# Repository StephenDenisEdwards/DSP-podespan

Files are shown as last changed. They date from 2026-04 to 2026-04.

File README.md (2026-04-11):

# DSP + DPS — Novostavba RD Edwards, Jevany

Complete building permit documentation (DSP — Dokumentace pro stavebni povoleni + DPS — Dokumentace pro provadeni stavby) for a new family house in Jevany, Czech Republic.

## Project Details

| | |
|---|---|
| **Project** | Novostavba rodinneho domu (New family house) |
| **Location** | Jevany [533378], k.u. Jevany [659312], parcels 154/10 and 154/16 |
| **Investor** | Bc. Marketa Edwards |
| **Design firm** | LUCERN DREVOSTAVBY s.r.o., Praha 4 - Branik |
| **Construction type** | Timber-frame (drevostavba), LUCERN EKO PLUS system |
| **Lead designer** | Ing. Josef Frydryn |
| **Authorized by** | Ing. Milos Slavik (2026-03-09) |
| **Elevation reference** | +/-0,000 = 397.402 m n. m. (Bpv) |

## Building Summary

Single-storey family house with attached garage on a sloping garden site (1,091 m2).

- **House footprint:** 180.38 m2
- **Usable area:** 142.07 m2 (4 bedrooms, open-plan living/kitchen, 2 bathrooms, utility room)
- **Terrace:** 38.18 m2
- **Garage:** 18.00 m2
- **Site coverage:** 15.67%
- **Remaining green area:** 84.33%

## Repository Structure

```
A. Pruvodni list/                  Cover / introductory report
B. Souhrnna technicka zprava/      Summary technical report
C. Situacni vykresy/               Site plans (C.1-C.4)
D.1. Dokumentace stavebniho objektu/
    D.1.1. Architektonicko stavebni cast/   Architecture (13 drawings)
    D.1.2. Stavebne konstrukcni cast/       Structural engineering
    D.1.3. Pozarni bezpecnost staveb/       Fire safety
    D.1.4. Technika prostredi staveb/
        D.1.4.1. Zdravotne technicke instalace/  Plumbing (5 docs)
        D.1.4.2. Vytapeni/                       Heating (2 docs)
        D.1.4.3. Elektroinstalace/               Electrical (3 docs)
        D.1.4.4. Nucene vetrani/                  Ventilation (2 docs)
E. Dokladova cast/                 Supporting documents
    GEOLOGICKY PRUZKUM/                Geological survey
    PENB/                              Energy performance certificate
    RADON/                             Radon report
_TITULKY/                          Title / cover pages
Documents/                         Analysis, tools, and working notes
    dwg-files/                         Survey plan (DXF/DWG) and tools
```

## Survey Plan & CAD Tools

The geodetic survey plan (`Documents/dwg-files/10225.dxf`) is the primary working file for site design. It contains terrain elevations, parcel boundaries, and existing features in S-JTSK coordinates.

**Tools included:**

- `visualize_dxf.py` — Generic DXF visualizer. Usage: `python visualize_dxf.py [file.dxf]`
- `create_site_plan.py` — Overlays the building footprint on the survey plan (approximate placement based on C.3 dimensions and elevation matching)

## Documents

| Document | Description |
|---|---|
| [Survey Plan Analysis](Documents/Survey%20Plan%20Analysis%20-%2010225.md) | Detailed analysis of the geodetic survey plan |
| [Swimming Pond - Project Design Document](Documents/Swimming%20Pond%20-%20Project%20Design%20Document.md) | Consolidated feasibility, geotechnical assessment, and technical design specification for the swimming pond |
| [CAD Workflow and File Status](Documents/CAD%20Workflow%20and%20File%20Status.md) | CAD file tracking, DXF analysis, coordinate system issues, and project context |
| [Natural Swimming Ponds Reference](Documents/reseach/natural-swimming-ponds-reference.md) | Comprehensive reference guide: design principles, construction, planting, regulations, costs (UK/EU) |
| [Image Generation Prompt](Documents/image-generation-prompt.md) | AI visualization prompt specifications for the house and pond |

## Key Site Data

| Parameter | Value |
|---|---|
| Site area | 1,091 m2 (parcels 154/10 + 154/16) |
| Terrain elevation | 392.7 - 399.6 m ASL |
| Slope | ~7 m fall over ~100 m (S to N) |
| Soil type | F5 ML (low-plasticity silt/clay), stiff consistency |
| Groundwater | ~7 m below ground |
| Soil permeability (kv) | 5.0 x 10-6 m/s |
| Radon index | HIGH |
| Coordinate system | S-JTSK (EPSG:5514) |

## Tools & Services

### Online Viewers

| Tool | URL | Purpose |
|---|-----|---|
| **Autodesk Viewer** | https://viewer.autodesk.com | Free online viewer for DWG, DXF, and PDF files — no software install required. Upload files to inspect layers, measure geometry, and navigate 2D/3D drawings in the browser. |

### CAD Software

| Tool | Purpose |
|---|---|
| **AutoCAD** | Industry-standard CAD software. The DWG files originate from AutoCAD (AC1027 / AutoCAD 2013 format). |
| **ODA File Converter** | Free tool from the Open Design Alliance for batch converting between DWG and DXF without an AutoCAD licence. Download from https://www.opendesign.com/guestfiles/oda_file_converter |

### Python Libraries

| Library | Purpose |
|---|---|
| **ezdxf** | Read, write, and manipulate DXF files programmatically. Used by `visualize_dxf.py` and `create_site_plan.py`. Install: `pip install ezdxf` |
| **matplotlib** | Plotting and PNG export of DXF visualizations. Install: `pip install matplotlib` |
| **numpy** | Numerical operations for coordinate and geometry processing. Install: `pip install numpy` |

### PDF Processing (optional)

| Library | Purpose |
|---|---|
| **pdfplumber** | Extract text and tables from PDF documents. Install: `pip install pdfplumber` |
| **PyPDF2** | PDF merging, splitting, and metadata extraction. Install: `pip install PyPDF2` |
| **PyMuPDF (fitz)** | High-performance PDF rendering and text extraction. Install: `pip install PyMuPDF` |

### Coordinate Systems

| System | Code | Description |
|---|---|---|
| **S-JTSK** | EPSG:5514 | Czech national geodetic coordinate system used in all survey and site plan files |
| **Bpv** | — | Baltic Vertical Datum — elevation reference for all height data |

## Source Files

The original project files are available at:
[Dropbox — DSP + DPS original files](https://www.dropbox.com/scl/fo/dlxxf2gikck120so64mw4/ANBmE9GKqDEZeK-OOHEcK_o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)

## Next Steps

1. Obtain remaining DWG files from LUCERN DREVOSTAVBY (see [CAD Workflow](Documents/CAD%20Workflow%20and%20File%20Status.md))
2. Create accurate combined site plan with exact building footprint
3. Design natural swimming pond layout on the DXF base

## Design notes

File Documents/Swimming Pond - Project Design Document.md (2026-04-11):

# Natural Swimming Pond (Schwimmteich) - Project Design Document

**Date:** 2026-04-11
**Site:** Parcels 154/10 and 154/16, Jevany [533378]
**Owner:** Bc. Marketa Edwards
**Coordinate system:** S-JTSK (Krovak)
**Elevation datum:** Bpv (Baltic after adjustment)

---

## Part A: Feasibility Assessment

### A.1 Key Documents and What to Use Them For

#### Primary Design Base

| Document | What it tells you | Priority |
|---|---|---|
| **10225.dxf** (survey plan) | Terrain elevations, parcel boundaries, existing features. Base drawing for design. | Essential |
| **C.3 Situace koordinacni** | Building footprint, utility routes, setbacks. Shows where things are and what space remains. | Essential |
| **Geologicky pruzkum** (E.) | Soil layers, permeability, groundwater depth. Determines feasibility and construction method. | Essential |

#### Supporting Information

| Document | What it tells you |
|---|---|
| **C.2 Situace celkova** | Parcel areas, neighbouring parcels, access, overall layout |
| **Radon report** (E.) | Soil gas permeability, confirms soil type across site |
| **D.1.4.1.4 Schema destove kanalizace** | Existing rainwater drainage routes; potential integration |
| **D.1.4.1.1 Technicka zprava** | Water supply connection, soakaway design, pipe routes |
| **D.1.1.1 Technicka zprava** | Building technical report, finished floor levels |

### A.2 Available Space

| Metric | Value |
|---|---|
| Total site area | 1,091 m² |
| House footprint | 180.38 m² |
| Paved areas + terrace + garage | 170.94 m² |
| Remaining green area | **739.68 m²** (approx.) |
| Green area percentage | 84.33% (per zoning) |

The site is elongated, running roughly NW-SE from Prazska street. The house sits toward the NW corner. The majority of open space is to the **east and southeast** of the building.

### A.3 Feasibility Factors

#### Factors in Favour

1. **Plenty of space** — 740 m² of green area; the proposed 75 m² pond uses only ~10% of available space
2. **Deep water table (7 m)** — no risk of groundwater contamination or buoyancy/flotation of an empty pond
3. **Stiff clay soil (F5 ML)** — naturally low permeability; clay soils are the best natural base for ponds
4. **No public stormwater sewer** — rainwater is already managed on-site; a pond could integrate with the existing retention/infiltration strategy
5. **Sloping terrain** — allows gravity-fed circulation between regeneration and swimming zones
6. **Granite-derived soil** — chemically neutral to slightly acidic; suitable for aquatic planting

#### Factors to Address

1. **Soil permeability (kv = 5 x 10⁻⁶ m/s)** — not zero; additional sealing required (see Part B §B.4)
2. **Terrain slope** — unequal cut depths; downhill side needs retaining solutions or naturalistic grading
3. **Fill material to 1.80 m** — upper soil is anthropogenic fill (navazka); pond base should reach natural clay below
4. **Existing utility routes** — electricity 82 m, water 81 m, sewer 40 m, rainwater 57 m; pond must clear these
5. **Radon** — HIGH index (72.3 kBq/m³); not a concern for open-air pond, but enclosed pump chambers would need protection
6. **Setbacks from boundaries** — Czech regulations typically require setbacks for water features; must confirm with stavebni urad (see Part B §B.6)
7. **Winter conditions** — Jevany at ~400 m ASL; hard frosts expected; sufficient depth (2.0 m) prevents freezing solid
8. **Building proximity** — pond at 0.1 m from terrace; pond floor ~1.2 m below house foundation base (see Part B §B.5)

---

## Part B: Geotechnical Assessment

**Purpose:** Consolidate all available geotechnical data relevant to the proposed swimming pond and identify gaps requiring further investigation.

### B.1 Data Sources

All soil and geotechnical data currently available originates from the **geological survey (geologicky pruzkum)** commissioned for the house construction, stored under `E. Dokladova cast / GEOLOGICKY PRUZKUM`. The raw survey report is not included in this repository.

**Important limitation:** All geotechnical data derives from **borehole S1**, which was drilled for the house foundation investigation. This borehole is not at the proposed pond location. The soil profile at the pond location has not been independently verified.

### B.2 Soil Classification and Profile

**Classification:** F5 ML — low-plasticity silt/clay, stiff consistency throughout.

#### Borehole S1 Profile

| Layer | Depth | Classification | Description |
|---|---|---|---|
| I | 0.00-0.10 m | F5 ML | Topsoil / humozni hlina (humic loam fill) |
| II | 0.10-1.80 m | F5 ML Y | Strongly sandy clay, stiff consistency. **Fill material (navazka)** with feldspar, quartz, mica from granite. |
| III | 1.80-2.00 m+ | F5 ML | Light brown/pinkish weakly sandy clay, stiff consistency. **Natural deluvial soil**, granite-derived. |

**Key characteristics:**
- The entire profile is F5 ML (low-plasticity silt/clay), stiff consistency
- Mineral content (feldspar, quartz, mica) derives from the underlying Ricany-type granite
- The upper 1.80 m is anthropogenic fill (navazka), not undisturbed ground
- Natural deluvial clay only begins below 1.80 m
- The fill material (Layer II) may have variable properties across the site

**Relevance to pond:** Excavation will reach ~2.5 m maximum, passing entirely through the fill and into natural clay. The natural clay provides a more stable base. Excavated spoil (F5 ML) is reusable for compacted clay liner, berms, or grading.

### B.3 Soil Permeability

| Parameter | Value | Standard |
|---|---|---|
| Infiltration coefficient (kv) | 5.0 x 10⁻⁶ m/s | CSN 75 9010 |
| Classification | Boundary between low and medium permeability | |
| Existing soakaway performance | 16 m² active area, 67.8 hours drain-down for 9.76 m³ retention | |

**Interpretation:** A kv of 5.0 x 10⁻⁶ m/s is not sufficient for a permanent pond without additional sealing. The liner or compacted clay must achieve kv < 10⁻⁸ m/s (two orders of magnitude tighter). Whether the on-site clay can be compacted to this level requires a Proctor compaction test.

**Data limitations:** The kv value comes from a single borehole (S1) at the house location. Permeability may differ at the pond location. No separate data exists for the natural clay layer (Layer III).

### B.4 Waterproofing Assessment

| Option | Suitability | Notes |
|---|---|---|
| **Compacted on-site clay** (min 300 mm) | Good — if Proctor test confirms kv < 10⁻⁸ m/s | Cheapest; most natural; uses excavated material. Viability unproven. |
| **Bentonite mat (GCL)** | Excellent | Self-healing; ~5-10 mm thick; reliable. Good backup for clay liner in critical areas. |
| **EPDM rubber liner** (1.0-1.5 mm) | Excellent | Standard for garden/swimming ponds; 20-30+ year life; most reliable option. Requires geotextile underlay. |
| **PVC-P (welded PVC sheets)** | Excellent | Common in Czech Republic (e.g. Alkorplan); often more cost-effective than EPDM; local installers familiar. |
| **Concrete with waterproof coating** | Overkill | Expensive; not typical for natural ponds; prone to freeze/thaw cracking; lime leaching raises pH. |

**Recommendation:** Test the on-site clay first. If it seals adequately after compaction, use compacted clay as the primary barrier with bentonite mat backup in critical areas. If clay does not achieve target permeability, use EPDM or PVC-P liner with geotextile underlay.

**Note on concrete:** Concrete lining is not necessary even at 2.0 m depth. The hydrostatic pressure at 2 m (~0.2 bar) is within the capability of EPDM/PVC-P liners. Concrete introduces risks (freeze/thaw cracking, lime leaching) without corresponding benefits.

### B.5 Building Proximity — Critical Structural Factor

The current design places the pond **0.1 m from the terrace edge**, directly adjacent to the house on the southeast side.

| Parameter | Value |
|---|---|
| Pond to terrace gap | 0.1 m (coping stone) |
| Terrace area | 38.18 m² |
| Pond swimming zone depth | 2.0 m (floor at 395.15 m Bpv) |
| Maximum excavation depth | ~2.5 m |
| House foundation type | Concrete strip foundations (základové pásy), C 16/20 - XC2 |
| Foundation deepest elevation | -1.050 m (relative to FFL 397.402 m Bpv = ~396.35 m Bpv) |
| Pond floor elevation | 395.15 m Bpv |

**The pond floor is approximately 1.2 m below the house foundation base.**

#### Structural Concerns

1. **Foundation influence zone** — Standard rule: excavation should not encroach within a 45-degree line from the base of an adjacent foundation. The pond excavation is ~1.45 m deeper than the foundation, and the 0.1 m gap is well within this zone.
2. **Lateral earth pressure** — The terrace and house impose surcharge loads. A 2.0-2.5 m deep excavation immediately adjacent removes passive resistance supporting the soil beneath.
3. **Construction phase risk** — The temporary open excavation during construction poses the greatest risk. An unsupported 2.5 m deep cut 0.1 m from the terrace could cause settlement.
4. **Water level fluctuation** — Filling/emptying cycles change lateral pressure on the terrace-side wall.

#### Construction Method by Side

| Pond Side | Expected Construction | Reason |
|---|---|---|
| **Terrace/house side (NW)** | **Reinforced concrete retaining wall** with liner over it | Pond floor ~1.2 m below foundation base; 0.1 m gap within 45-degree influence zone |
| **Other three sides (NE, SE, SW)** | **Liner-only** (EPDM, PVC-P, or compacted clay) on graded 1:3 slopes | No adjacent structural loads; stiff clay (per S1) holds graded slopes. Subject to confirmation by soil test. |

**Alternative:** Moving the pond 2-3 m from the terrace (clearing the foundation influence zone) could eliminate the need for concrete entirely.

#### Decision Flowchart

```
Pond-location borehole + trial pit
        |
        v
Soil stiff and consistent (matches S1)?
    |                   |
   YES                  NO
    |                   |
    v                   v
Liner-only          Where is the instability?
construction            |
(EPDM/PVC-P/       +-----------+-----------+
compacted clay)     |           |           |
                Localised    Widespread   Soft/wet
                soft fill    loose fill   throughout
                    |           |           |
                    v           v           v
                Localised   Partial      Full concrete
                retaining   concrete     shell or
                wall/gabion retaining    alternative
                            walls        site location
```

### B.6 Boundary Setback Constraints

Czech building regulations typically require setbacks for water features, estimated at **2-3 m from parcel boundaries**. This has **not been confirmed** for Jevany.

| Question | Where to get the answer |
|---|---|
| Minimum setback from parcel boundaries for a water feature? | Územní plán obce Jevany and/or stavební úřad |
| Is the pond classified as a stavba (structure)? | Stavební úřad Jevany |
| Does permit type (ohlášení vs. stavební povolení) affect setbacks? | Stavební úřad Jevany |
| Additional zoning restrictions on water features? | Územní plán obce Jevany |

The setback requirement may force pond repositioning, which in turn affects whether concrete is needed on the house side.

### B.7 Geology, Groundwater, and Radon

| Parameter | Value |
|---|---|
| Bedrock | Ricany-type granite |
| Minerals | Feldspar, quartz, mica |
| Chemical character | Neutral to slightly acidic (suitable for aquatic planting) |
| Water table depth | ~7 m below ground surface |
| Aquifer type | Fracture-controlled, granite bedrock |
| Radon index | HIGH (72.3 kBq/m³) |
| Gas permeability | Medium |

No groundwater interference at excavation depth (2.0-2.5 m). Radon dissipates freely in open water/air — not a concern for the pond itself. Enclosed pump chambers would need radon protection.

### B.8 Terrain and Slope

| Parameter | Value |
|---|---|
| Elevation range (site) | 392.72 m to 399.60 m ASL (Bpv) |
| Overall slope | ~7 m fall from south (street) to north, over ~100 m |
| Finished floor level (house) | +/-0,000 = 397.402 m Bpv |
| Finished ground level | 397.152 m Bpv |
| Terrain around building | 396.8-398.7 m Bpv |
| Local slope at pond | ~2 m fall toward the southeast |

Excavation on a slope means unequal cut depths. The slope is an advantage for gravity-fed circulation. Excavated spoil can build up the downhill side.

### B.9 Excavation Estimates

| Parameter | Value |
|---|---|
| Maximum excavation depth | ~2.5 m (swimming zone + liner base) |
| Estimated volume | 110-130 m³ |
| Spoil material | F5 ML clay |
| Spoil reuse | Compacted liner, landscaping berms, slope grading |

Excavation will pass through fill (0-1.80 m) into natural deluvial clay below. The fill/natural clay boundary at ~1.80 m should be visually confirmed during excavation — the natural clay is light brown/pinkish and weakly sandy, distinct from the darker fill above.

### B.10 Outstanding Investigations

#### Priority 1 — Required Before Final Design

| Investigation | Purpose | Notes |
|---|---|---|
| **Structural engineering assessment** | Assess pond excavation vs. house strip foundations | Pond is 0.1 m from terrace; floor ~1.2 m below foundation base. Must determine if concrete retaining wall is needed or if pond should be moved. |
| **Geotechnical borehole at pond location** | Verify soil profile; test permeability at actual pond site | Borehole to 3+ m with in-situ permeability testing. Also determines construction method for non-building sides. |
| **Proctor compaction test** | Can excavated clay be compacted to kv < 10⁻⁸ m/s? | Determines viability of compacted clay liner (cheapest option). |
| **Trial pit at pond location** | Visual confirmation of soil layers, fill depth, and clay interface | Can be combined with borehole investigation. |
| **Boundary setback confirmation** | Verify minimum distances from parcel boundaries | Consult stavební úřad Jevany and check územní plán. Directly constrains pond positioning. |

#### Priority 2 — Required Before Construction

| Investigation | Purpose |
|---|---|
| Utility route survey | Confirm exact positions of underground services at pond location |

#### Priority 3 — Recommended

| Investigation | Purpose |
|---|---|
| Water source quality test | Confirm mains water suitability for initial fill (pH, hardness, chlorine) |
| Rainwater quality assessment | Evaluate roof runoff quality for pond top-up use |

### B.11 Summary of Key Soil Parameters

| Parameter | Value | Confidence |
|---|---|---|
| Soil classification | F5 ML (low-plasticity silt/clay) | High |
| Consistency | Stiff | High |
| Fill depth | 0-1.80 m (navazka) | Medium — may vary across site |
| Natural clay depth | 1.80 m+ | Medium — may vary across site |
| Permeability (kv) | 5.0 x 10⁻⁶ m/s | Medium — single test, single location |
| Groundwater depth | ~7 m | High |
| Bedrock | Ricany-type granite | High |
| Radon index | HIGH (72.3 kBq/m³) | High |

**Overall assessment:** Site conditions are **favourable** for a natural swimming pond. The main uncertainty is whether on-site clay can be compacted to a sufficient seal — requires the Proctor test. If not, EPDM or PVC-P liner provides a proven alternative.

---

## Part C: Design Specification

### C.1 Design Overview

A rectangular natural swimming pond (Schwimmteich) positioned adjacent to the existing terrace on the southeast side of the house. The pond uses biological filtration through aquatic plants and gravel substrate to maintain water quality without chemical treatment.

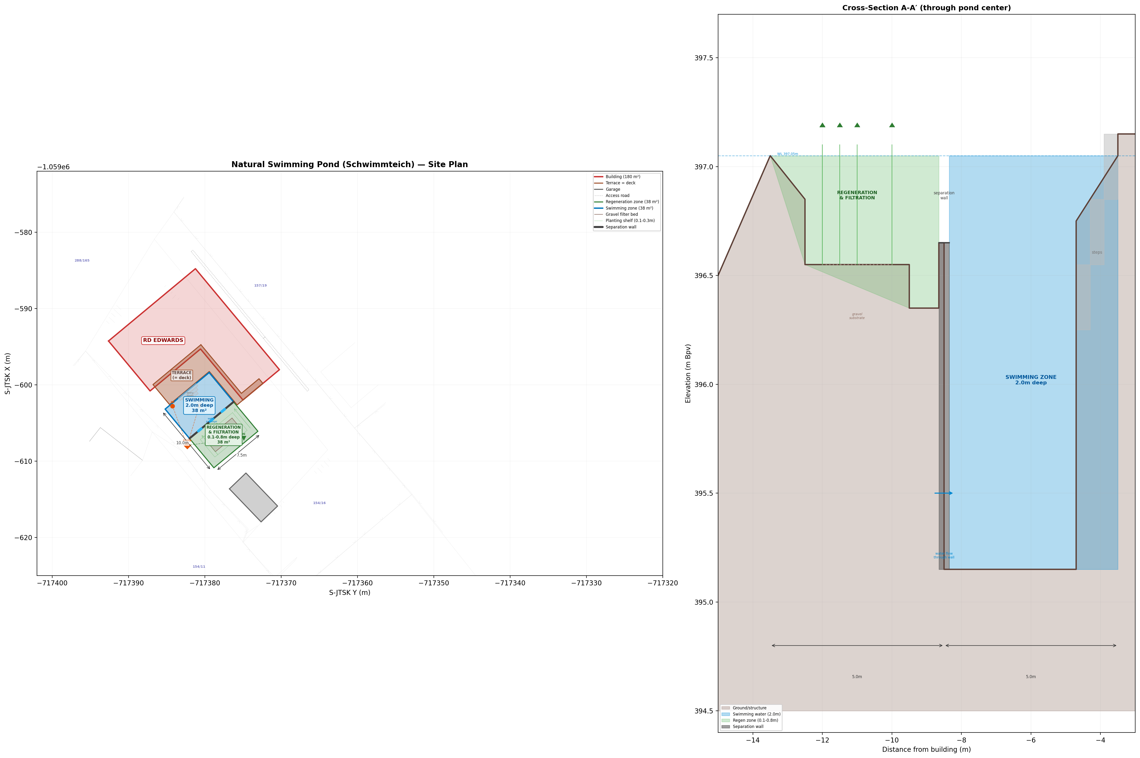
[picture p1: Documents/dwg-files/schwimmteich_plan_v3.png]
Site Plan

*Figure 1: Site plan (left) and cross-section A-A' (right) showing pond position relative to building and terrace.*

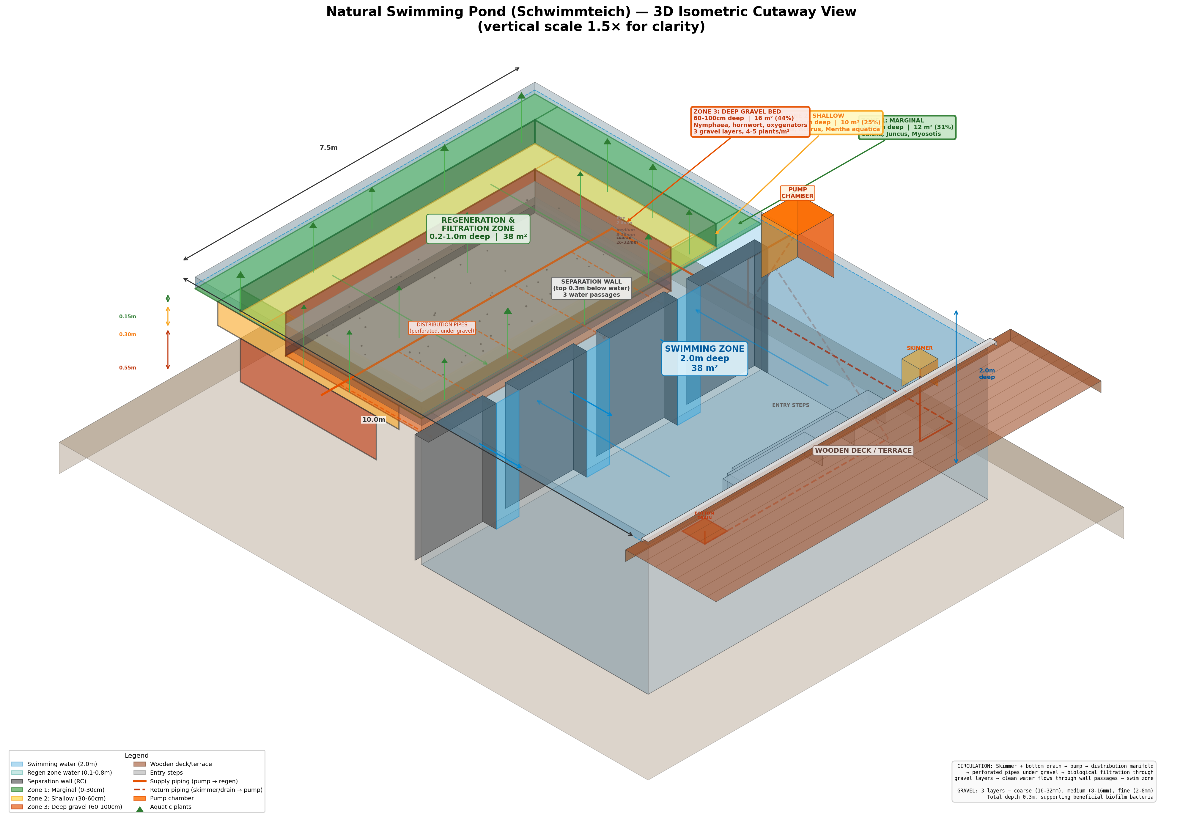
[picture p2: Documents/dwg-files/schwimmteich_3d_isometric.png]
3D Isometric

*Figure 2: 3D isometric cutaway view showing internal structure, depth zones, separation wall, gravel substrate, and circulation piping.*

### C.2 Dimensions and Zone Areas

#### Overall Pond

| Parameter | Value |
|---|---|
| Overall dimensions | 10.0m x 7.5m |
| Total pond area | 75 m² |
| Swimming : Regeneration ratio | 1:1 (50:50) |
| Position | 0.1m gap from terrace edge (coping stone) |

The 1:1 ratio follows the standard rule-of-thumb. UK/EU guidance suggests the swim area should not exceed 50-70% of total water surface, with a common target of equal area split.

#### Swimming Zone

| Parameter | Value |
|---|---|
| Dimensions | 5.0m x 7.5m |
| Area | 38 m² |
| Depth | 2.0m (floor at 395.15m Bpv) |
| Water level | 397.05m Bpv (0.10m below terrace) |
| Terrace level | 397.15m Bpv |

The 2.0m depth provides thermocline stability, comfortable swimming, and protection against freezing solid.

#### Regeneration Zone

| Parameter | Value |
|---|---|
| Dimensions | 5.0m x 7.5m |
| Total area | 38 m² |
| Depth range | 0-100cm (three stepped zones) |

### C.3 Regeneration Zone - Depth Zoning

Three stepped depth zones support maximum plant diversity and optimise biological filtration. Zones are arranged as concentric rings.

| Zone | Depth | Width | Area | % of Regen | Purpose |
|---|---|---|---|---|---|
| **Zone 1: Marginal** | 0-30cm | 0.5m ring | ~12 m² | ~31% | Emergent edge plants |
| **Zone 2: Shallow** | 30-60cm | 0.5m ring | ~8 m² | ~22% | Mid-depth aquatics |
| **Zone 3: Deep gravel bed** | 60-100cm | Centre | ~18 m² | ~47% | Submerged oxygenators + biological filtration |

#### Zone 1: Marginal (0-30cm)

Outermost ring, 0.5m wide. Supports emergent plants with roots in saturated substrate, foliage above waterline.

**Recommended plants:** Marsh Marigold (*Caltha palustris*), Soft Rush (*Juncus effusus*), Water Forget-me-not (*Myosotis scorpioides*), Flowering Rush (*Butomus umbellatus*), Creeping Jenny (*Lysimachia nummularia*)

#### Zone 2: Shallow (30-60cm)

0.5m wide ring inside the marginal zone. Larger aquatic plants with deeper root systems.

**Recommended plants:** Yellow Flag Iris (*Iris pseudacorus*), Sweet Flag (*Acorus calamus*), Water Mint (*Mentha aquatica*), Pickerel Weed (*Pontederia cordata*)

#### Zone 3: Deep Gravel Bed (60-100cm)

Largest zone, centre of regeneration area. Layered gravel substrate provides primary biological filtration. Supports fully submerged oxygenators and water lilies.

**Recommended plants:** Hardy Water Lily (*Nymphaea alba*), Hornwort (*Ceratophyllum demersum*), Water Crowfoot (*Ranunculus aquatilis*), Water Milfoil (*Myriophyllum spicatum*)

**Planting density:** 4-5 plants per m², aiming for 100% cover of shallow beds by summer.

### C.4 Gravel Substrate

The deep gravel bed (Zone 3) contains a layered substrate for biofilm bacteria. Total depth approximately 0.3-0.4m.

| Layer | Position | Grain size | Purpose |
|---|---|---|---|
| Coarse | Bottom | 16-32mm | Drainage, structural support, pipe protection |
| Medium | Middle | 8-16mm | Transition layer, additional biofilm surface |
| Fine | Top | 2-8mm | Planting substrate, maximum biofilm surface area |

All gravel must be washed, lime-free, and chemically inert. Locally quarried granite gravel would be chemically compatible. Limestone gravel must be avoided (raises pH, disrupts biological filtration).

### C.5 Separation Wall

A reinforced concrete wall divides the swimming zone from the regeneration zone.

| Parameter | Value |
|---|---|
| Material | Reinforced concrete or masonry |
| Thickness | 0.30m |
| Wall top | 0.40m below water surface (396.65m Bpv) |
| Wall base | Pond floor level (395.15m Bpv) |
| Water passages | 3 openings, each 0.5m wide |

The wall top sits below the waterline for surface-level water exchange while preventing swimmer access to the regeneration area. The three base passages allow circulation flow after filtration.

### C.6 Circulation System

#### Flow Path

```
Swimming Zone -> Skimmer (surface) + Bottom Drain (deep) -> Pump Chamber ->
Distribution Manifold -> Perforated Pipes (under gravel) ->
Biological Filtration (through gravel layers) ->
Clean water flows through wall passages -> Swimming Zone
```

#### Components

| Component | Position | Function |
|---|---|---|
| **Skimmer (SK)** | Swimming zone, near terrace, surface level | Collects surface debris |
| **Bottom Drain (BD)** | Swimming zone floor, centre | Deep water circulation, removes settled sediment |
| **Pump Chamber** | Outside pond, adjacent to separation wall | Houses pump, accessible for maintenance |
| **Distribution Manifold** | Under gravel, far end of regen zone | Distributes water evenly across gravel bed |
| **Perforated Branch Pipes** | Under gravel, perpendicular to manifold | Even distribution through substrate |
| **Wall Passages** | 3 openings in separation wall | Return filtered water to swimming zone |

#### Pump Sizing

| Parameter | Value |
|---|---|
| Estimated pond volume | ~100 m³ |
| Target turnover | 12-24 hours |
| Required flow rate | ~4,200-8,300 L/h |

### C.7 Entry and Access

Three graduated steps descend from the terrace into the swimming zone:

| Step | Width | Depth below terrace |
|---|---|---|
| Step 1 | 3.0m | 0.30m |
| Step 2 | 2.4m | 0.60m |
| Step 3 | 1.8m | 0.90m |

Steps narrow progressively and are centred on the terrace edge. Non-slip surface finish required.

The existing 38 m² terrace serves as the pool deck. A coping stone edge (0.1m gap) separates the terrace from the pond water.

### C.8 Elevations

| Feature | Elevation (m Bpv) |
|---|---|
| Terrace / deck level | 397.15 |
| Water level | 397.05 |
| Separation wall top | 396.65 |
| Zone 1 floor (marginal, 0-30cm) | ~396.90 |
| Zone 2 floor (shallow, 30-60cm) | ~396.60 |
| Zone 3 floor (deep gravel, 60-100cm) | ~396.05 |
| Swimming zone floor | 395.15 |

### C.9 Utilities

- Connect overflow to existing rainwater drainage system (D.1.4.1.4)
- Pump electrical supply from house (D.1.4.3)
- Maintain clearance from underground sewer route (D.1.4.1.2)
- All pipe penetrations through the liner must be welded or mechanically sealed

### C.10 Water Quality Targets

No chemical treatment. Water quality maintained entirely through biological filtration.

| Parameter | Target | Standard |
|---|---|---|
| *E. coli* | ≤100 CFU/100 mL | FLL (German) guidelines |
| pH | 6.5-8.5 (target 7.0-7.5) | FLL guidelines |
| Water hardness | 8-12° dH | FLL guidelines |
| Phosphate | Minimised (no fertiliser runoff) | BANSP/IOB |

All surface runoff and fertiliser from surrounding land must be excluded. Even small amounts of lawn fertiliser can overload the system with phosphorus and trigger algal blooms.

### C.11 Maintenance Summary

| Task | Frequency |
|---|---|
| Skim surface debris | Daily/as needed |
| Check pump and skimmer | Weekly |
| Test water quality (pH, nutrients) | Monthly |
| Trim and cut back dead plant growth | Autumn |
| Remove accumulated sediment | Annually |
| Deep clean and inspect liner | Annually (spring) |
| Lamp replacement (if UV fitted) | As needed |

---

## Part D: Regulatory Checklist

### Before Design

- [ ] Check **uzemni plan obce Jevany** for restrictions on water features, maximum zastavena plocha, minimum zelena plocha
- [ ] Confirm whether a natural swimming pond requires **ohlaseni stavby** or **stavebni povoleni** with local stavebni urad
- [ ] Check **minimum setback distances** from parcel boundaries (typically 2-3 m)
- [ ] Confirm the existing soakaway location — pond should not be placed above or adjacent to it
- [ ] Verify utility routes on C.3 — mark exclusion zones for all underground pipes

### Soil & Water Testing

- [ ] Commission **geotechnical investigation** at pond location (borehole to 3+ m, permeability testing)
- [ ] **Proctor compaction test** on site clay to confirm liner viability
- [ ] **Trial pit** at proposed location to verify soil profile
- [ ] **Structural engineering assessment** of building proximity (see Part B §B.5)

### Design Phase

- [ ] Survey proposed pond area using **10225.dxf** as base
- [ ] Design pond geometry — swimming zone, regeneration zone, shelves, slopes
- [ ] Calculate **cut/fill volumes** from terrain model
- [ ] Design waterproofing (clay liner, GCL, or EPDM)
- [ ] Design circulation system (pump, pipework, planting plan)
- [ ] Plan **overflow drainage** — connect to existing soakaway?
- [ ] Consider **rainwater diversion** from roof to pond for top-up
- [ ] Plan electrical supply for circulation pump
- [ ] Design safety measures (fencing if required, depth markers, edge treatment)

### Integration with Existing Project

- [ ] Coordinate with **SO-03** (destove vody / stormwater) — potential to redirect some roof runoff to pond
- [ ] Ensure pond does not conflict with **SO-05** (zpevnene plochy / paved areas, terrace)
- [ ] Check **fire hazard zone (PNP)** from C.3 does not conflict with pond placement
- [ ] Verify adequate distance from **soakaway** (min. 5 m from buildings per geological report)

---

## Part E: Next Steps

1. **Walk the site** with the C.3 coordination plan and survey data to identify the best pond location
2. **Commission targeted geotechnical investigation** at the chosen location — borehole to 3 m with in-situ permeability testing and Proctor compaction test
3. **Commission structural engineering assessment** of pond excavation vs. house foundations
4. **Consult the stavebni urad Jevany** about permit requirements and boundary setbacks
5. **Start design on the DXF** — draw pond geometry, calculate volumes, produce drawings

---

## Part F: Reference Data

### Site Data at a Glance

| Parameter | Value |
|---|---|
| Total site area | 1,091 m² |
| Available green space | ~740 m² |
| Terrain slope | ~7 m fall over ~100 m (S to N) |
| Soil type | F5 ML (low-plasticity silt/clay), stiff |
| Fill depth | 0-1.80 m (anthropogenic fill) |
| Natural clay | below 1.80 m (deluvial) |
| Groundwater | ~7 m below ground |
| Soil permeability (kv) | 5.0 x 10⁻⁶ m/s |
| Radon index | HIGH (not relevant for open pond) |
| Elevation reference | +/-0,000 = 397.402 m Bpv |
| Existing stormwater | On-site soakaway, 9.76 m³ retention, 16 m² infiltration area |
| Water supply | PE-MD 40x5.5 mm from public main |
| Electricity | Existing connection, low-voltage |

### Design Summary

| Parameter | Value |
|---|---|
| **Total pond area** | 75 m² (10.0m x 7.5m) |
| **Swimming zone** | 38 m² at 2.0m deep |
| **Regeneration zone** | 38 m² in 3 depth zones |
| — Zone 1 (marginal) | ~12 m² at 0-30cm |
| — Zone 2 (shallow) | ~8 m² at 30-60cm |
| — Zone 3 (deep gravel) | ~18 m² at 60-100cm |
| **Swim:Regen ratio** | 1:1 |
| **Separation wall** | RC, 0.30m thick, 3 passages |
| **Gravel substrate** | 3 layers (coarse/medium/fine) |
| **Circulation** | Skimmer + bottom drain -> pump -> gravel bed -> wall passages |
| **Water treatment** | Biological only (no chemicals) |
| **Planting density** | 4-5 plants/m² |
| **Pump turnover** | 12-24 hours full volume |

### Drawing References

| Drawing | Description |
|---|---|
| `schwimmteich_plan_v3.dxf` | Site plan with pond layout in S-JTSK coordinates |
| `schwimmteich_plan_v3.png` | Site plan visualisation with cross-section |
| `schwimmteich_3d_isometric.png` | 3D isometric cutaway showing internal structure |
| `combined_site_plan.dxf` | Combined site plan with building, garage, roads |
| `10225.dxf` | Original survey plan (base drawing) |

### Key Standards Referenced

- **FLL** (Forschungsgesellschaft Landschaftsentwicklung Landschaftsbau) — German guidelines for natural swimming pond water quality
- **BANSP/IOB** — British Association of Natural Swimming Pools / Institute of Builders — UK trade guidelines
- **CSN 75 9010** — Czech standard for infiltration coefficient testing

### Source Documents (Geological Survey)

| Document | Location |
|---|---|
| Geological Survey (original) | `E. Dokladova cast/GEOLOGICKY PRUZKUM/` (not in repository) |
| Radon Report | `E. Dokladova cast/` (referenced, not in repository) |
| Survey Plan Analysis | `Documents/Survey Plan Analysis - 10225.md` |

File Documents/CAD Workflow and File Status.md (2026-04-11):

# CAD Workflow and File Status

**Date:** 2026-04-08 (updated 2026-04-10)
**Purpose:** Track CAD file acquisition from LUCERN, document analysis results, and enable site design work (landscaping, swimming pond).

---

## 1. Project Overview

This repository contains the complete building permit documentation (DSP + DPS) for a new family house in Jevany, Czech Republic.

- **Project:** Novostavba rodinneho domu (New family house)
- **Location:** Jevany [533378], parcels 154/10 and 154/16
- **Investor:** Bc. Marketa Edwards, K dalnici 167, Pitkovice, 104 00 Praha 10
- **Design firm:** LUCERN DREVOSTAVBY s.r.o., Udolni 280/15, Praha 4 - Branik
- **Construction type:** Timber-frame (drevostavba), LUCERN EKO PLUS system
- **Lead designer:** Ing. Josef Frydryn
- **Drafter:** Ing. Vaclav Kepelak, DiS.
- **Authorization:** Ing. Milos Slavik (digitally signed 2026-03-09)
- **Stage:** DSP + DPS
- **Elevation reference:** +/-0,000 = 397.402 m above sea level (Bpv)

The repository contains ~45 PDF files organized into standard Czech building documentation sections:

| Section | Description |
|---|---|
| A. Pruvodni list | Cover/introductory report |
| B. Souhrnna technicka zprava | Summary technical report |
| C. Situacni vykresy (C.1-C.4) | Site plans |
| D.1.1. Architektonicko stavebni cast (13 drawings) | Architecture - plans, sections, elevations |
| D.1.2. Stavebne konstrukcni cast | Structural engineering |
| D.1.3. Pozarni bezpecnost staveb | Fire safety |
| D.1.4.1. Zdravotne technicke instalace (5 docs) | Plumbing |
| D.1.4.2. Vytapeni (2 docs) | Heating |
| D.1.4.3. Elektroinstalace (3 docs) | Electrical |
| D.1.4.4. Nucene vetrani (2 docs) | Mechanical ventilation |
| E. Dokladova cast | Supporting documents (geology, radon, PENB) |
| _TITULKY | Title/cover pages |

---

## 2. File Status

| File | Status | Notes |
|---|---|---|
| 10225.dxf | **Available** | Survey plan (polohopisny a vyskopisny plan) — in S-JTSK absolute coordinates, fully analyzed |
| 10225.dwg | **Available** | Same survey plan in DWG format |
| All PDFs | **Available** | Complete set of ~45 PDFs — text/dimensions extractable, but graphical content (shapes, layouts) not accessible |
| C.3. Koordinacni situace.dwg/.dxf | **Received 2026-04-10** | Coordination site plan. Paper space coordinates (mm), NOT S-JTSK. |
| C.2. Celkovy situacni vykres.dwg/.dxf | **Received 2026-04-10** | Overall site plan. Paper space coordinates (mm), NOT S-JTSK. |
| D.1.1.3. Pudorys 1. NP.dwg/.dxf | **Received 2026-04-10** | Ground floor plan. Local coordinates (mm), near origin. |

---

## 3. Outstanding File Requests

Request the **original DWG files** for all remaining drawings. Every PDF in the documentation package was created from a DWG — the architect has them.

### Priority 2 — Important for site design

| Drawing | PDF name | Why we need it |
|---|---|---|
| **D.1.1.2 Pudorys zakladu** | D.1.1.2. Pudorys zakladu.pdf | Foundation plan — exact footprint at ground level, drainage pipes, radon protection. Relevant for understanding what's underground near the building. |
| **D.1.1.8 Pudorys zakladu garaze** | D.1.1.8. Pudorys zakladu garaze.pdf | Garage foundation plan — exact garage footprint. |
| **D.1.1.9 Pudorys 1. NP garaze** | D.1.1.9. Pudorys 1. NP garaze.pdf | Garage floor plan — exact garage shape. |
| **C.1 Situace sirsich vztahu** | C.1. Situace sirsich vztahu.pdf | Wider context plan — surroundings, access, neighbouring features. |
| **C.4 Situace podpisova** | C.4. Situace podpisova.pdf | Signed site plan — may have additional annotations or corrections. |

### Priority 3 — Useful for detailed design

| Drawing | PDF name | Why we need it |
|---|---|---|
| **D.1.1.5 Rez A-A** | D.1.1.5. Rez A-A.pdf | Cross-section — finished ground levels, floor levels, terrain relationship. |
| **D.1.1.6 Pohled severni/jizni** | D.1.1.6. Pohled severni_jizni.pdf | Elevations — finished ground line around the house. |
| **D.1.1.7 Pohled vychodni/zapadni** | D.1.1.7. Pohled vychodni_zapadni.pdf | Elevations — other directions. |
| **D.1.4.1.2 Schema lezate kanalizace** | D.1.4.1.2. Schema lezate kanalizace.pdf | Underground drainage layout — pipe routes to avoid when excavating. |
| **D.1.4.1.4 Schema destove kanalizace** | D.1.4.1.4. Schema destova kanalizace.pdf | Rainwater drainage — potential integration with swimming pond. |
| **D.1.4.3.3 Schema hromosvodu** | D.1.4.3.3. Schema hromosvodu.pdf | Lightning protection — earthing routes that may cross the garden. |

### How to Request

> *"Dobrý den, mohli byste nám prosím poskytnout originální DWG soubory k projektové dokumentaci RD Edwards, Jevany? Potřebujeme je pro návrh zahradních úprav a koupacího jezírka. Především potřebujeme koordinační situaci (C.3), celkovou situaci (C.2) a půdorys 1. NP (D.1.1.3). Ideálně všechny výkresy, pokud je to možné."*

Translation:
> *"Hello, could you please provide us with the original DWG files for the RD Edwards project documentation, Jevany? We need them for designing the garden landscaping and a swimming pond. We primarily need the coordination site plan (C.3), overall site plan (C.2), and the ground floor plan (D.1.1.3). Ideally all drawings, if possible."*

### Format Notes

- **DWG is preferred** — native AutoCAD format, preserves everything (layers, blocks, dimensions, hatching, paper space layouts)
- **DXF is also acceptable** — fully interchangeable with DWG, though some formatting may be simplified
- Files should be in **S-JTSK / EPSG:5514** — ask whether site plans were drawn in absolute S-JTSK coordinates or a local coordinate system

---

## 4. DXF Analysis Results (2026-04-10)

### Tool Setup

- **ezdxf 1.4.3** (Python library) — installed and verified 2026-04-08
- Enables programmatic reading, editing, and creation of DXF files

### C.3. Koordinacni situace (Coordination site plan)

- **DXF version:** AC1027 (AutoCAD 2013)
- **Units:** mm
- **Layers:** 12 (including BT_mapove_znacky, BT_hranice_parcel, BT_hranice_budov, BT_vnitrni_kresby, BT_text_parcel, BT_prvky_mapy, Situace - koordinační)
- **Entities:** 801 (453 LWPOLYLINE, 164 MTEXT, 53 CIRCLE, 39 DIMENSION, 33 HATCH, 30 INSERT, 29 ARC)
- **Extents:** Min (405930, -271768) to Max (619733, -128588) — paper space layout, ~214m x 143m sheet
- **Coordinate system:** Paper space (mm), NOT S-JTSK

### C.2. Celkovy situacni vykres (Overall site plan)

- **DXF version:** AC1027
- **Units:** mm
- **Layers:** 10 (similar BT_ survey layers as C.3)
- **Entities:** 287 (146 LWPOLYLINE, 40 MTEXT, 33 CIRCLE, 31 DIMENSION, 30 INSERT, 7 HATCH)
- **Extents:** Min (155930, -269476) to Max (369733, -128588) — paper space layout
- **Coordinate system:** Paper space (mm), NOT S-JTSK

### D.1.1.3. Pudorys 1. NP (Ground floor plan)

- **DXF version:** AC1027
- **Units:** mm
- **Layers:** 24 (Konstrukce - svislé nosné, Otvory – Okna, Otvory – Dveře, Interiér - nábytek, Kóty - SP, etc.)
- **Entities:** 420 (142 DIMENSION, 100 LWPOLYLINE, 95 INSERT, 58 MTEXT, 18 CIRCLE, 7 HATCH)
- **Extents:** Min (-2870, -19566) to Max (17163, 9870) — ~20m x 29m, local coordinates near origin
- **Coordinate system:** Local model coordinates (mm)

### Survey plan reference (10225.dxf)

- **Extents:** Min (-717399, -1059683) to Max (-717317, -1059575) — ~82m x 108m
- **Coordinate system:** S-JTSK absolute (EPSG:5514)

---

## 5. Coordinate System Issue

The LUCERN drawings are in paper/layout coordinates (mm), not S-JTSK. Direct overlay on the survey plan is not possible without transformation.

**Approaches:**
1. **Ask LUCERN for S-JTSK versions** — request the model-space drawings in absolute S-JTSK coordinates, or ask for the xref/block of the survey underlay they used.
2. **Manual alignment** — extract the building footprint from C.3 and place it on the survey plan using known reference points and setback dimensions. Work on this is underway.

---

## 6. Documents Examined from PDFs

### D.1.1.2. Pudorys zakladu (Foundation Plan)

- **Foundation type:** Concrete strip foundations (zakladove pasy) in C 16/20 - XC2 concrete with reinforced concrete slab (ZB deska)
- **Key elevations:** -0,150 / -0,330 / -0,580 / -1,050 m
- **Overall dimensions:** ~16.9 m x 14.5 m (outer edge of foundation slab)
- **Radon protection:** Perforated drainage pipes DN 60 under slab, vented through foundation side
- **Drainage:** Perforated drainage pipes around perimeter with collection pipes
- **Penetrations:** Sewer, water + electrical, fresh air supply for fireplace

### D.1.1.3. Pudorys 1. NP (1st Floor Plan)

Single-story house with total usable area of **142.07 m²** plus a **38.19 m² terrace**.

| Room | Area | Floor |
|---|---|---|
| 1.01 Zadveri (Entrance) | 8.90 m² | Ceramic tile |
| 1.02 Technicka mistnost (Utility) | 4.14 m² | Ceramic tile |
| 1.03 Koupelna + WC (Bathroom 1) | 3.78 m² | Ceramic tile |
| 1.04 Obyvaci pokoj + KK (Living + kitchen) | 49.11 m² | Wood |
| 1.05 Spiz (Pantry) | 4.16 m² | Wood |
| 1.06 Pokoj 1 (Bedroom 1) | 11.28 m² | Wood |
| 1.07 Koupelna + WC (Bathroom 2) | 11.22 m² | Ceramic tile |
| 1.08 Pokoj 2 (Bedroom 2) | 17.11 m² | Wood |
| 1.09 Loznice (Master bedroom) | 19.26 m² | Wood |
| 1.10 Satna (Walk-in closet) | 6.38 m² | Wood |
| 1.11 Chodba (Hallway) | 6.72 m² | Wood |

**Wall types:**
- **W6 (Exterior):** Silicone facade + EPS 160mm + KVH 60/120 studs + mineral insulation + vapor barrier + battens 40/60 + Rigistabil. Total ~357 mm.
- **W1 (Interior load-bearing):** Rigistabil + KVH 60/120 + insulation + Rigistabil. Total 145 mm.
- **W2 (Interior non-load-bearing):** Rigistabil + KVH 60/80 + insulation + Rigistabil. Total 105 mm.

**Key features:** Chimney DN 270, hidden blind cassettes on most windows, heat pump in utility room, skylight 900x1200 in living room.

---

## 7. What We Can Do With the DWGs

1. Extract the exact building footprint from C.3 and overlay it on the survey plan
2. Create an accurate combined site plan (survey + building + utilities) as base for landscaping design
3. Design the swimming pond with precise positioning relative to the house, boundaries, and utilities
4. Calculate exact excavation volumes using the terrain elevation data
5. Plan utility integration (rainwater diversion to pond, electrical for circulation pump)

---

## 8. Next Steps

1. ~~Obtain Priority 1 DWG files from LUCERN~~ **Done (2026-04-10)**
2. ~~Export as DXF~~ **Done (2026-04-10)**
3. ~~Analyze DXF files with ezdxf~~ **Done (2026-04-10)**
4. Request S-JTSK coordinate versions from LUCERN
5. Extract building footprint from C.3 and manually align to survey plan
6. Create combined site plan (survey + building + utilities) as base for landscaping design
7. Request remaining Priority 2-3 DWG files

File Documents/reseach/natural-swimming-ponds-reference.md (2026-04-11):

# Natural Swimming Ponds — Comprehensive Reference Guide

## Executive Summary

Natural swimming ponds (NSPs) are chemically-free pools that use ecological design — aquatic plants, gravel filters and beneficial microbes — to maintain water quality. UK trade guidelines (BANSP/IOB) require NSPs to be fully sealed (isolated from ground) and rely only on mechanical/biological purification, forbidding biocides. In practice this means separating the pool into a **swimming zone** and adjacent **regeneration (filter) zones** planted with wetland vegetation. Roughly half the pond's area is typically a planted filter, whose flora and associated biofilms consume nutrients (nitrogen, phosphorus) and suppress algae. Well-designed NSPs aim for neutral pH, drinking-water hardness, and low faecal indicator counts (e.g. ≤100 CFU/100 mL *E. coli* as per FLL standards).

This reference guide covers design principles, sizing and zoning, construction methods, filtration options, planting palettes by depth zone, water chemistry, hydraulic calculations, UK safety/regulatory issues, accessibility, maintenance regimes, cost ranges, implementation steps, and case studies from UK/EU projects.

---

## 1. Design Principles and Ecology

Natural ponds function as **self-sustaining ecosystems**. They replace chlorine with *biological* cleaning: aquatic plants and biofilms filter out organics and nutrients. Key design principles (per BANSP/IOB) include:

- **Sealed construction** — the pool must be fully isolated from surrounding ground to avoid groundwater seepage
- **Zoned layout** — separate swimming zone from planted treatment zones
- **No biocides** — only mechanical and biological treatment
- **Inert materials** — construction materials must not leach pollutants
- **Exclude runoff** — all fertiliser and surface runoff from surrounding land must be kept out (even a few grams of lawn fertiliser can overload the system with phosphorus and trigger algal blooms)
- **No fish or ducks** — to avoid nutrient loading

Ecologically, a pond provides habitat and biodiversity. Its design often includes logs, rocks and shallow "beaches" to support wildlife (frogs, newts, insects), while avoiding invasive exotics. Materials should follow circular-economy principles (reused/recycled). NSP water quality can match strict standards: studies show biofilters can reduce pathogens and nutrient loads to meet WHO bathing guidelines. In operation, NSPs conserve water and energy: the water is never dumped (aside from top-ups) and small pumps suffice.

---

## 2. Sizing and Zoning

### Two Main Zones

| Zone | Purpose | Typical depth |
|---|---|---|
| **Swimming zone** | Deep, clear water for bathing | 1.5-2.5 m |
| **Regeneration zone** | Shallow, planted area for biological filtration | 0.3-1.0 m |

### Proportions

- Swim area should not exceed ~50-70% of total water surface
- Common rule-of-thumb: **1:1 ratio** swim:plant area
- UK designers typically make swim zone at least 35-50 m² for effective use
- Larger facilities (100-300 m²+) are common for multiple users

**Examples:**
- Biotop UK family pool: 140 m² swim zone + 75 m² filter
- Lincolnshire project: 111 m² swim + 168 m² regeneration (total 279 m²)
- 40 m² swimming at 2-3 m depth with equal 40 m² regen at ~1 m depth

### Depth Guidelines

| Zone | Recommended Depth | Notes |
|---|---|---|
| Swimming zone | 1.5-2.5 m | Stability, thermocline, diving (if ≥2.5 m). Deep bottom drain recommended. |
| Shallow beaches/steps | 0.2-0.5 m | Improve access for children and mobility-impaired |
| Regeneration beds | 0.3-1.0 m | German/US guides cite 0.6-1 m of gravel depth for bacteria |

### Layout Guidelines

- Strictly separate human/swim zones from treatment zones (per BANSP/IOB)
- Provide surface skimmers and drains in the swim area
- Direct overflow or pump suction to the filter area
- Ensure gentle hydraulic flow between zones (aerated waterfall or spillway)
- Avoid shade or runoff from roofs/trees falling into the regeneration zone
- Place pond with ample sunlight and clear of overhanging trees
- Hardscape: non-slip surfaces, handrails where needed
- Accessibility features: gentle ramps, wide steps, hoists or sloped entries

---

## 3. Construction Methods and Materials

### Excavation and Structure

The pool is excavated to prescribed depths, then sealed. The base must be fully isolated from surrounding ground. Common sealing methods:

| Material | Description | Advantages | Disadvantages |
|---|---|---|---|
| **EPDM Rubber** | Flexible synthetic membrane (≥1.0 mm) | Very durable (30+ years), flexible, UV/ozone resistant, seam-weldable. Relatively quick to install. | Higher material cost. Must guard against punctures. |
| **Concrete Shell** | Cast reinforced concrete basin with sealant | Extremely robust; integrates steps, seats, finishes. Virtually maintenance-free. | Very high construction cost. Requires skilled labour and longer curing. Prone to cracking (freeze/thaw). Lime leaching can raise pH. |
| **Bentonite Clay** | Natural clay layer (sodium bentonite) compacted under liner | Natural, non-toxic, self-healing seal if intact. | Works only with high-clay soils. Very sensitive to drying. Thick layer needed (≥10 cm). |
| **PVC-P** | Welded PVC sheets | Common in Central Europe; cost-effective; local installers familiar. | Less flexible than EPDM; shorter lifespan. |

**Example:** The Lincolnshire natural swimming pond (2015) used reinforced concrete walls and floor, lined with a black TPO membrane, with sandstone coping and timber decking.

### Substrate Layers

In planted zones, a layered substrate is placed over the liner:
1. Geotextile fabric over liner
2. Graded gravel bed (coarse at bottom, fines at top), 0.6-1.0 m total depth
3. Optional thin layer of sand/organic soil on top for planting

The gravel supports bacteria and anchors plant roots. In the swim zone, the liner may be covered with non-slip tiles, plaster, or left bare.

### Plumbing and Fittings

- At least one skimmer (surface suction) and main drain in swim area
- Pump(s) sized for 12-48 hour turnover
- Pipes feed the regeneration zone via overflow (weir/spillway) or direct pumping
- Electrical supply and bonding per UK wiring regs (Part P, 18th Edition)
- Optional UV or phosphate filters downstream of biological filter
- All penetrations through liner must be welded or mechanically sealed

---

## 4. Filtration Systems

Natural pools employ **multiple filtration stages**, prioritising biological processes.

### Options Comparison

| System | How It Works | Advantages | Considerations |
|---|---|---|---|
| **Planted Regeneration Zone** | Water flows through gravel and plant roots. Biofilms consume organics; plants absorb N, P. | Fully natural; creates habitat and aesthetic. Chemical-free. Low running cost. | Requires ≥30-50% of area. Takes weeks to establish. Seasonal plant management needed. |
| **Biofilter (Media)** | Pumped water through engineered media (sand, matrix, mineral beds). Bacteria on media degrade organics. | Compact, reliable nutrient removal. Works continuously. Good for specific pollutants (e.g. phosphate). | Needs power and plumbing. Media clogs — requires periodic backwashing. |
| **Mechanical/Skimmer** | Skimmers and fine filters capture debris. | Immediate removal of leaves, suspended solids. | Energy costs. Doesn't remove nutrients. |
| **UV Steriliser** | Inline UV lamp kills microbes in flow. | Kills algae/bacteria; chemical-free. Rapid clarity. | No residual effect. Requires clear water upstream. Can harm beneficial biofilter bacteria if overused. Lamp replacement. |
| **Ozonator** | Ozone gas injection oxidizes bacteria, viruses, organics. | Very strong disinfection. No chemical leftovers (ozone reverts to O₂). | No lasting sanitiser. Expensive equipment. Safety considerations. Mixing/degassing needed. |
| **Phosphate Media** | Mineral media (e.g. PhosTec, Phoslock) to bind phosphate. | Lowers nutrient levels; helps prevent algae. | Consumable (needs periodic replacement). |

### Design Models

Fluidra identifies three approaches:
- **"Pure Nature"** — large planted wetland only (no mechanical filter)
- **"Natural"** — plants + low-power filter + UV
- **"Crystal"** — full filtration with backwash for crystal clarity

In practice, many ponds use a **hybrid system**: a large planted filter as primary, supplemented by a small UV or phosphate filter for extra clarity.

### Circulation

- Target: 50-100% of pool volume per day (full turnover in 12-48 hours)
- Higher flows help during summer or after rain
- Place return jet to promote complete mixing
- Surface skimmers and fixed bottom drains together maximise debris collection

```mermaid
flowchart LR
    SW["Swimming Zone"] -->|"Skimmer\n(40-60% flow)"| Pump[Pump & Filter]
    Pump --> RG["Regeneration Zone\n(planted gravel)"]
    RG --> SW
    RG -->|Aeration| Atmos[(Air)]
```
*Figure: Water circulation in a natural pond.*

---

## 5. Planting Palettes by Depth Zone

Aquatic planting is chosen for both aesthetics and filtration function. Use native UK/European species — no invasives, no tropical exotics.

### Deep Water Zone (60 cm+)

Fully submerged or floating plants. Oxygenators and shade providers.

| Species | Common Name | Function |
|---|---|---|
| *Ceratophyllum demersum* | Hornwort | Oxygenator |
| *Ranunculus aquatilis* | Water Crowfoot | Oxygenator |
| *Myriophyllum spicatum* | Water Milfoil | Oxygenator |
| *Nymphaea alba* | Hardy Water Lily | Shade (suppresses algae), aesthetics |
| *Aponogeton distachyos* | Water Hawthorn | Flowering oxygenator (mild areas only) |

### Shallow Water Zone (30-60 cm)

Marginal aquatics with dense roots that stabilise banks and uptake nutrients.

| Species | Common Name | Function |
|---|---|---|
| *Pontederia cordata* | Pickerel Weed | Purple flowers, nutrient uptake |
| *Iris pseudacorus* | Yellow Flag Iris | Strong nutrient uptake, bank stabilisation |
| *Acorus calamus* | Sweet Flag | Aromatic, nutrient uptake |
| *Mentha aquatica* | Water Mint | Fine nutrient uptake, fragrant |

### Marginal Zone (0-30 cm)

Emergent plants at the water's edge. Roots in saturated substrate, foliage above waterline.

| Species | Common Name | Function |
|---|---|---|
| *Caltha palustris* | Marsh Marigold | Yellow spring blooms |
| *Juncus effusus* | Soft Rush | Structural, bank stabilisation |
| *Myosotis scorpioides* | Water Forget-me-not | Edge softening, blue flowers |
| *Butomus umbellatus* | Flowering Rush | Pink flowers, wildlife |
| *Lysimachia nummularia* | Creeping Jenny | Ground cover |
| *Ranunculus flammula* | Lesser Spearwort | Edge planting |
| *Lythrum salicaria* | Purple Loosestrife | Tall, purple spikes |
| *Filipendula ulmaria* | Meadowsweet | Fragrant, attracts pollinators |
| *Typha latifolia* | Bulrush | Tall, structural |
| *Carex* spp. | Sedges | Edge planting, diversity |

### Planting Guidelines

- **Density:** 4-5 plants per m² in regeneration beds (1 m spacing)
- **Goal:** ~100% cover of shallow beds by summer
- At least one-third of water surface should be planted
- Plant in spring (April-June) to establish
- Group by depth requirements; consider spring vs. summer flowering
- Keep swim area free of large plants
- Dense planting at edges provides year-round habitat and privacy
- In autumn, cut back dead growth and remove debris to avoid nutrient release
- Overwintering is natural (plants go dormant, roots remain)

### UK Suppliers

- Waterside Nursery
- Devon Pond Plants (~5 plants/m² recommended, ~£20-30/m²)
- Park Corner Aquatic / Park Corner Nurseries
- Roots Plants

---

## 6. Water Chemistry and Balance

### Nutrients (N, P)

Phosphates are the main enemy. Plants and filters should remove nearly all P. External sources must be minimised:
- Avoid fertiliser or runoff
- Remove leaves and organic debris promptly
- Seed biofilter with beneficial bacteria in spring (commercial "pool starter" products)

### pH and Hardness

- Target pH: 6.5-8.5 (NSPs often settle near 7.0-7.5)
- Hardness: ~8-12° dH (per FLL recommendations)
- Test fill/drinking water chemistry before filling (per BANSP)
- After filling, test pH, total alkalinity and hardness monthly

### Microbial (Hygiene)

- Biofilters "cleanse" pathogens through beneficial biofilms
- German FLL guideline (2017): max 100 CFU/100 mL *E. coli*
- Public pools: regular testing for *E. coli*, enterococci, *P. aeruginosa* is mandated
- Private: test periodically (quarterly or after contamination)
- If faecal contamination occurs: short pool closure or emergency UV shock

### Algae Control

- Some planktonic/string algae is normal and seasonal
- Good circulation, plant cover (lilies shade light), regular skimming prevent blooms
- Barley straw is an eco-friendly algicide (releases humic compounds)
- Increasing plant cover or circulation usually resolves green water
- A bit of clear algae often indicates a healthy ecosystem

### Testing Regime

- Test fill and make-up water for minerals/contaminants (per BANSP)
- Monthly: pH, nitrates, phosphates
- Rising P indicates an outside source
- Public facilities: weekly lab tests per Bathing Water Regulations (2013)
- Private: in-house dipslide kits and occasional lab checks
- Keep a log of water chemistry and maintenance

---

## 7. Hydraulics and Pump Sizing

### Turnover Guidelines

- Recirculate entire pond volume at least every 12-24 hours
- 1-2 turnovers per day is common practice
- Higher flows during summer or after rain

### Sizing Formula

```
Required flow (L/h) = Volume (L) / Desired turnover time (h)
```

### Example Calculations

| Pond | Volume | Turnover | Required Flow |
|---|---|---|---|
| Small (50 m², avg 1.5m) | 75 m³ | 12 h | ~6,250 L/h |
| Medium (100 m³) | 100 m³ | 12 h | ~8,300 L/h |
| Large (200 m² swim + 200 m² regen) | 600 m³ | 12 h | ~50,000 L/h |

For the large example, a practical design might use a pump rated 20-30 m³/h continuously (for ~2x turnover/day) plus smaller gravity flow to filter beds.

### Design Notes

- Always add head (pipe friction, elevation) and use pump curves
- Flow is typically split: some through vegetation beds by gravity, most pumped through filter
- Circulation prevents stagnation and distributes oxygen
- Very high flows can disturb shallow plants — balance is needed
- All pump wiring must be on GFCI/RCD circuits

---

## 8. Safety and Regulations (UK/EU Context)

### Structural Safety

- Permanent pool construction requires Building Regulation approval (England/Wales)
- No specific UK standard for "natural pools" — NSP builders follow BS EN 15288 (pool safety) and BS 8510 (non-slip finishes)
- The NSP is treated like an engineered pool for structural purposes

### Barriers and Access

- No legal UK minimum for domestic pool fencing
- **RLSS UK recommends:** secure barrier ≥1.2 m high with self-closing gates to prevent unsupervised child access
- Best practice: 1.2-1.5 m enclosure/gate
- Gaps must be small (no footholds), climbing-resistant
- All stairs and ramps should be slip-resistant
- Designs compliant with Equality Act and BS 8300 (pool lifts, wide slopes)

### Signage and Safety Equipment

- Standard signs: "No Lifeguard — Swim at Your Own Risk", depth warnings, "No Diving" if shallow
- British Standard signage (EN ISO 7010)
- Post rules near pond (no glass, supervision rules)
- Rescue equipment: pole, ring buoy
- Alarm system and emergency instructions recommended

### Supervision

- RLSS: never allow children <16 to swim without an adult (typically 2:1 adult:child ratio)
- PWTAG: discourage lone bathing
- Commercial/public ponds: lifeguards with RLSS or STA qualifications required
- Private: optional but good practice for groups

### Electrical Safety

- Pumps and lights: Part P of UK wiring regulations (18th Edition)
- All motors bonded/earthed as for pools
- GFCI/RCD protection on circuits
- Underwater lights: safe low-voltage transformers

### Water Quality Regulation

- Private natural pond is not a statutory "bathing water"
- No automatic requirement for lifeguard or shower
- If open to public/club members: local health authority inspections apply
- King's Cross Pond Club (London) operates under strict European Bathing Water standards with lifeguard, changing rooms

### Planning Permission

- Most garden ponds do not need planning permission
- Check if in protected area (AONB, listed building) or if significant structures involved
- Check with local council
- In Czech Republic: check whether ohlášení stavby or stavební povolení is required

### Other

- Noise from pumps must meet environmental limits
- Waste water from backwashing must go to foul drain (not storm drains)

---

## 9. Accessibility

- At least one gently graded entry (beach or ramp) for less-abled swimmers
- Paths and deck surfaces: wide, level, non-slip
- Handrails or pool lifts in deeper sections for elderly/wheelchair users
- Seating at varying heights adjacent to water
- Avoid vertical drop-offs or hidden ledges
- All equipment in lockable, covered housing to avoid trip hazards

---

## 10. Maintenance Schedules

### Seasonal Routine

| Season | Tasks |
|---|---|
| **Spring** | Clear winter debris (leaves, algae mats). Start pumps/filters. Prune dead plant material, divide overcrowded plants. Test water chemistry (pH, nitrates, phosphates). Top up with dechlorinated water. Seed biofilter with bacteria starters. Lay barley straw if needed. |
| **Summer** | Skim daily/weekly for debris. Trim encroaching plants. Monitor water levels (evaporation ~5 mm/day); refill with rainwater or dechlorinated tap water. Inspect pumps, clean skimmer baskets weekly. If cloudy, add more oxygenating plants or shade (float lilies). |
| **Autumn** | Fit leaf net or barrier in October. Cut back most plants to just above water. Inspect and clean pumps/filters. Test water quality. |
| **Winter** | No draining needed (UK/mild climates). Keep a small hole in any ice for gas exchange. Run pumps on timer or use floating de-icer. Check after storms. |

### Regular Checklist

- **Weekly (summer) / Monthly (winter):** skim debris, empty skimmer baskets, check pump, inspect UV bulb (if installed), monitor plant health
- **Annual "spring clean":** vacuum sediment from swim floor, add new plants if sparse, replace some filter media

### Time Commitment

Most owners spend **15-30 minutes/week** in summer (vs. 2-4 hours for chlorinated pools). An annual professional service is recommended.

### Annual Service Includes

Full vacuuming of substrate, cleaning liners, replacing filter media, inspecting pump/UV, water testing. Every 3-5 years a deep clean may involve fully draining the pool.

### Algae Troubleshooting

- Green water (planktonic algae): increase plant cover or circulation
- Blanketweed (filamentous): manually remove; reduce phosphate input (avoid tap water top-ups)
- Add more oxygenating plants or use pond vacuum
- UV or ozone can break algae cycles when needed
- A bit of clear algae is normal and indicates a healthy ecosystem

---

## 11. Cost Estimates (UK, 2025-26)

### By Scale

| Scale | Swim Area | Filter Area | Total Area | Indicative Cost (GBP) |
|---|---|---|---|---|
| Small wildlife pond | — | ~25 m² | ~50 m² | £10k-£20k |
| Small swim pond | 30-50 m² | 20-40 m² | 50-90 m² | from ~£60k |
| Medium swim pond | ~150 m² | ~100 m² | ~250 m² | ~£90k |
| Large family pond | ~300 m² | ~200 m² | 500 m²+ | >£120k |

### Cost Breakdown (Example: 50 m² swim pond)

| Item | Typical Cost |
|---|---|
| Excavation & site prep | £10-20k |
| EPDM Liner (50 m²) | ~£3-5k |
| Pump/Filter system | £10-25k |
| Aquatic plants (plants/soil) | ~£5-10k |
| Decking/Hardscape | £5-15k (optional) |
| **Total (50 m² swim pond)** | **~£60k+** |
| **Large estate pond** | **£100k+** |

### Cost Factors

- Site access (difficult sites need heavy equipment)
- Ground type (heavy clay vs. rock excavation)
- Liner choice
- Design features (stone coping, decking, waterfalls)
- Professional design fees (~£500-2,500)
- Local planning fees (if needed)

### Running Costs

- Annual maintenance: **£300-£1,000/year** (electricity and occasional plant replacement)
- Budget rule: ~£1,000-£1,500 per m² of total pond (budget installation); elaborate projects double that
- Planting budget is roughly equal to liner cost

---

## 12. Implementation Checklist and Timeline

### Build Phases

1. **Design & Permitting (2-6 weeks):** Engage NSP designer/landscaper. Finalise plan. Obtain planning approvals.
2. **Excavation (1-2 weeks):** Dig swimming and regeneration zones. Slope edges. Divert surface water.
3. **Liner Installation (1-3 weeks):** Apply waterproofing (EPDM, bentonite, or concrete). Ensure full sealing.
4. **Plumbing & Electrical (1 week):** Install pump(s), pipes, skimmers, drains. Run electrical feeds.
5. **Filter Beds & Substrate (1 week):** Lay geotextile and graded gravel. Add substrate layer.
6. **Planting (1-2 days):** Install aquatic plants. Mulch around roots.
7. **Filling & Start-up (4-8 weeks):** Fill slowly. Start pumps. Over 4-8 weeks, bacteria colonise. Monitor clarity. Cloudiness is normal.

**Total: 2-4 months**, weather permitting.

```mermaid
gantt
    title Swimming Pond Build Schedule
    dateFormat  YYYY-MM-DD
    section Design & Permits
    Consultation & Concept :done, a1, 2025-05-01, 3w
    Detailed Design         :done, a2, after a1, 3w
    Permitting             :done, a3, after a2, 4w
    section Construction
    Excavation             :active, b1, after a3, 2w
    Liner/Structure        :b2, after b1, 5d
    Pump & Plumbing        :b3, after b2, 4d
    Gravel/Filter Setup    :b4, after b3, 4d
    section Finishing
    Backfill & Landscaping :b5, after b4, 1w
    Planting Vegetation    :b6, after b5, 1w
    section Commissioning
    Water Fill & Testing   :c1, after b6, 3d
    Handover               :c2, after c1, 2d
```

### Seasonal Notes

- Ideal to finish planting in spring for growth
- If built in colder months, run pumps and cover plants until warm
- Before winter, follow autumn maintenance steps

---

## 13. Case Studies (UK/EU)

### Lincolnshire Family Pool (2015)
A 16x6 m concrete pond (2.0 m deep) with 111 m² swim area and 168 m² planted zone (279 m² total). Built by Ellicar Pools using reinforced concrete with black TPO liner and sandstone coping. Planted with water mint, reeds and natives. Sandy beach for shallow entry. Won a design award for crystal-clear water.

### King's Cross Pond Club (London, 2015)
The UK's first public natural pool — a 40 m outdoor pond in central London. Operates 24/7 with lifeguards, changing rooms and showers. Water treated by marginal plants and biofilter. Crystal-clear year-round. Follows all bathing-water hygiene guidelines.

### West Sussex Private Pond
A 12x4 m fibreglass-style pond by Biotop. Band of iris and rush around edges for filtration, cedar deck. Crystal-clear water, no chemical treatment.

### Kent Swimming Pond
Family pond with beach entry and submerged step. Undergravel filtration and small biofilter. *Iris pseudacorus* and *Lythrum* ring the shallow shelf.

### Buckinghamshire Natural Pool
Shallow gravel "beach" and pool house. Heavily planted regeneration zone (flag iris, cow parsley). Skimmer feeds hidden gravel filters under deck. Won a local landscaping award.

### Hertfordshire Rectangular Pond
Modern formal design with stone edges. EPDM liner and wooden-glass-bead filters. Native plants at edges, habitat for newts.

### Naturbad Riehen (Basel, Switzerland)
Large public "swimming pond" in a park. Swim area + broad wetland regeneration with reeds and lagoon beds. Sand filters and UV for public health standards.

### Residential Examples
- Doncaster (2010): 140 m² swim + 75 m² filter
- Surrey: ~100 m² garden pond achieving fishable clarity using only plants
- Austrian/German/Swiss hotel pools (often heated) with similar designs

---

## 14. UK Suppliers and Resources

### Designers / Contractors
- **BANSP** (British Association of Natural Swimming Ponds) — member directory
- **The Swimming Pond Company** (Norfolk)
- **Ellicar Gardens** (London)
- **Clear Water Revival**
- **Biotop** (UK)

### Plant Suppliers
- Devon Pond Plants
- Waterside Nursery
- Park Corner Nurseries
- Roots Plants

### Equipment
- **BioNova** (UK) — filters
- **Certikin** — pool equipment, UV
- **Filcoten Aqua / Vision Pools** — liners
- **Firestone** — EPDM liners
- **AquaMax / BioNova** — pumps
- **Del Ozone** — ozone generators

### Standards and Guidelines
- **BANSP/IOB** — UK trade association guidelines
- **FLL** (Germany) — water quality standards for natural pools
- **PWTAG** — Pool Water Treatment Advisory Group
- **RLSS** — Royal Life Saving Society (safety)
- **BS EN 15288** — Pool safety in operation
- **BS 8510** — Non-slip finishes

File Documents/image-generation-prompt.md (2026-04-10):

# Image Generation Prompt — LUCERN House with Natural Swimming Pond (Schwimmteich)

## Context

- Single-story modern timber-frame house (LUCERN EKO PLUS system), Jevany, Czech Republic
- Flat roof, white silicone render exterior with horizontal timber cladding (larch/thermowood)
- Large floor-to-ceiling glazing, covered terrace with outdoor dining
- Rectangular natural swimming pond (Schwimmteich) extending from the terrace toward the garden
- The existing stone/concrete terrace serves as the pool deck — no separate wooden deck
- Pond is divided into a clear swimming zone (near the terrace) and a planted regeneration/filtration zone (far side), separated by a submerged wall
- Viewpoint: standing at the back of the house, looking southeast across the terrace and pond
- Terrain slopes gently downhill (~2m over 15m) from terrace toward the garden — pond is partially in-ground
- Surrounded by mature deciduous and conifer trees (Central European forest edge)
- Late afternoon golden-hour light, summer

## Reference images

- `images/lucern-house-jevany.jpeg` — the house style (architecture, materials, terrace)
- `images/natural-swimming-pond-jevany.jpeg` — the pond style (water clarity, planting, natural stone, atmosphere)

---

## Midjourney Prompt

Upload both reference images to Midjourney first, then use their image URLs in the prompt:

```
[upload lucern-house-jevany.jpeg] [upload natural-swimming-pond-jevany.jpeg] Combine these two references: the modern single-story house architecture from the first image with a natural swimming pond inspired by the second image, but rectangular. Photorealistic architectural visualization, eye-level view from the covered terrace looking southeast across the garden. The house exactly as shown in image 1 — flat roof, white render with horizontal timber cladding, floor-to-ceiling glass doors, covered terrace with dark dining furniture. The stone terrace serves as the pool deck, with three wide entry steps descending directly from the terrace into a rectangular natural swimming pond (10m x 7.5m). The near half of the pond is a clear swimming zone with crystal turquoise water and a visible gravel bottom, 2 meters deep. A low submerged concrete wall divides the pond at the midpoint. The far half is a shallow regeneration and filtration zone filled with aquatic plants — water lilies, native reeds, rushes, iris, and submerged oxygenating plants growing from a gravel substrate. Natural stone coping borders the pond edges. The terrain slopes gently downhill from the terrace. A matching flat-roofed garage is partially visible 15 meters away beyond the pond. Mature spruce trees, birches, and oaks frame the background, Czech countryside forest edge. Lush green lawn around the pond. Late afternoon golden sunlight, long shadows, warm summer atmosphere. 35mm lens, architectural photography --ar 16:9 --v 6.1 --style raw --sw 200
```

> **Note:** `--sw 200` (style weight) increases the influence of the reference images. Adjust between 100-500. You can also use `--cref` and `--sref` flags for character/style references in newer Midjourney versions.

### Alternative: using /describe + /blend

1. `/describe` each image to get Midjourney's interpretation
2. `/blend` both images together as a starting point
3. Then refine with `/imagine` using the text prompt above

---

## DALL-E / ChatGPT Prompt

In ChatGPT with DALL-E, upload both images to the conversation first, then send:

```
I've uploaded two reference images:
1. A modern single-story house — this is the exact house style I want (flat roof, white render + horizontal timber cladding, floor-to-ceiling glass, covered terrace with dark furniture)
2. A natural swimming pond — this is the water/planting style I want (clear water, natural stone borders, aquatic plants, natural atmosphere)

Create a photorealistic architectural visualization that combines both, but with a RECTANGULAR pond design (a Schwimmteich / natural swimming pool):

Viewpoint: standing on the covered terrace of the house from image 1, looking out southeast across the garden.

The scene should show:
- The house terrace (as in image 1) in the immediate foreground — the covered section with timber ceiling, the concrete/stone paved terrace area
- The terrace IS the pool deck — no separate wooden deck. Three wide stone entry steps descend directly from the terrace edge into the swimming zone
- A rectangular natural swimming pond, 10m long x 7.5m wide, aligned with the building axis
- The NEAR HALF (closest to the terrace) is a clear swimming zone — crystal turquoise water, 2m deep, visible gravel bottom, clean and inviting
- A low submerged separation wall (visible as a subtle line just below the water surface) divides the pond at the midpoint
- The FAR HALF is a regeneration and biological filtration zone — shallower (0.3-0.8m), filled with aquatic plants growing from a gravel substrate: water lilies (Nymphaea), native reeds (Phragmites), rushes, yellow iris (Iris pseudacorus), marsh marigold (Caltha), and submerged oxygenating plants
- Natural stone coping (cut stone or large flat rocks) borders all four edges of the rectangular pond
- The terrain slopes gently downhill from the terrace toward the far edge — the pond is partially set into the ground, with the terrace at the high side
- Lush green lawn around the pond, with some ornamental grasses
- Mature spruce trees, birches, and oaks in the background (Central European forest edge, similar atmosphere to image 2)
- A separate flat-roofed garage building (matching the house style — white render, flat roof) partially visible to the right, about 15 meters from the terrace, beyond the pond
- No fencing or pool barriers

Lighting: late afternoon golden hour, warm summer sunlight casting long shadows. Clear sky. Czech countryside, Jevany (east of Prague).

Style: photorealistic architectural photography, 35mm lens perspective, professional real-estate / architectural magazine quality. The image should feel warm, aspirational, and serene.
```

---

## Stable Diffusion Prompt (with IP-Adapter for image references)

Use IP-Adapter or ControlNet to feed both reference images, then apply this prompt:

```
(masterpiece, best quality, photorealistic:1.3), architectural exterior photography,
modern single-story house with flat roof, white render and horizontal timber cladding,
floor-to-ceiling glass doors, stone terrace as pool deck with entry steps into water,
rectangular natural swimming pool Schwimmteich with crystal clear turquoise water,
near half clear deep swimming zone visible gravel bottom,
far half shallow regeneration zone with aquatic plants water lilies reeds iris growing from gravel substrate,
low submerged separation wall dividing swimming and regeneration zones,
natural stone coping bordering rectangular pond,
view from covered terrace looking southeast across pond,
(lush green garden:1.1), mature spruce trees birch trees oak trees in background,
Czech countryside forest edge setting,
gentle slope downhill from terrace, pond partially set into ground,
flat-roofed garage building visible in distance,
golden hour late afternoon sunlight, warm summer atmosphere, long shadows,
35mm lens, shallow depth of field, architectural photography
Negative prompt: cartoon, illustration, painting, sketch, ugly, deformed, blurry, low quality, watermark, text, kidney shape, organic shape, round pool, wooden deck
```

> **Setup:** Use IP-Adapter with `lucern-house-jevany.jpeg` at weight 0.6 for architectural style, and `natural-swimming-pond-jevany.jpeg` at weight 0.5 for the water/planting style. Use a depth ControlNet if you have a 3D mockup.

---

## Key Design Details for Reference

| Element | Dimension | Notes |
|---|---|---|
| Total pond area | 75 m2 | Rectangular, aligned with building axis |
| Swimming zone | 38 m2 (5.0m x 7.5m) | 1.9m deep, clear water, gravel bottom |
| Regeneration zone | 38 m2 (5.0m x 7.5m) | 0.1-0.8m deep, planted with native aquatics on gravel substrate |
| Separation wall | 7.5m long | Reinforced concrete, top 0.4m below water surface, 3 water passages |
| Pond overall | 10.0m x 7.5m | Long axis perpendicular to building |
| Deck / terrace | 38 m2 (existing) | Stone/concrete, serves as pool deck |
| Entry steps | 3 steps | 0.3m, 0.6m, 0.9m graduated from terrace into swim zone |
| Pond to garage | ~3m clearance | |
| Terrain drop | ~2m | From terrace (397.2m Bpv) to far edge (395.2m Bpv) |
| Water level | 397.05m Bpv | 0.1m below terrace surface |
| Building orientation | ~40 deg from N | Long axis runs NW-SE |
| Circulation | Skimmer + bottom drain → pump → return to regen zone | Low-energy, chemical-free |

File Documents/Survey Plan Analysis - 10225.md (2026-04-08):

# Survey Plan Analysis - 10225.dxf / 10225.dwg

**Date:** 2026-04-08

## File Summary

| Property | Value |
|---|---|
| Filename | 10225.dxf (282 KB) / 10225.dwg (56 KB) |
| AutoCAD version | AC1027 (AutoCAD 2013) |
| Code page | ANSI_1252 (Central European Windows) |
| Last saved by | steph |
| Drawing type | 2D (all Z = 0.0) |
| Coordinate system | S-JTSK (Czech national geodetic system) |

## What This Drawing Is

This is a **polohopisny a vyskopisny plan** (planimetric and altimetric survey plan) — a standard Czech geodetic survey deliverable. It documents the site at parcel 154/11 and surroundings in Jevany, produced by a licensed surveyor (geodet) as part of the building permit documentation.

The drawing shows:

1. **Cadastral parcel boundaries** with parcel numbers from the Czech land registry
2. **Terrain elevations** at ~93 measured points (392-400 m ASL), indicating a gently sloping site (~7 m drop over ~100 m)
3. **Existing infrastructure** — roads, sidewalks, driveways, vegetation
4. **Survey control network** — benchmarks, reference points, situational points
5. **Coordinate grid** in S-JTSK with labeled tick marks

## Spatial Extent

- **X range:** -717,399 to -717,317 (~82 m)
- **Y range:** -1,059,683 to -1,059,575 (~108 m)
- **Viewport center:** -717,368.7, -1,059,608.0
- **Elevation range:** 392.72 m to 399.60 m ASL (Bpv)

## Layers

All 14 layers use AutoCAD color index 7 (white/black). The numeric names follow the Czech geodetic feature coding standard:

| Layer | Entity Count | Meaning |
|---|---|---|
| 1 | 432 | Cadastral boundaries (hranice parcel) |
| 23 | 189 | Survey/height points (vyskove body) |
| 41 | 97 | Height value text annotations |
| 22 | 96 | Elevation labels (vyskove koty) |
| 25 | 25 | Geodetic control points (geodeticke body) |
| 4 | 19 | Buildings / structures (budovy) |
| 0 | 15 | Default layer |
| 61 | 12 | Coordinate grid (souradnicova sit) |
| 18 | 9 | Parcel number labels (cisla parcel) |
| 26 | 7 | Trees (stromy) |
| 19 | 3 | Additional parcel labels |
| 16 | 1 | Misc |

Two additional named layers exist but carry no entities: `CONSTRUCTION_CLASS`, `PATTERN_CLASS`.

## Entities (874 total in model space)

| Type | Count | Role |
|---|---|---|
| LINE | 488 | Parcel boundaries, building edges, grid lines |
| TEXT | 220 | Labels — parcel numbers, elevations, surface types |
| INSERT | 136 | Survey symbol block references |
| ARC | 12 | Curved boundaries, building details |
| CIRCLE | 10 | Part of blocks, manholes |
| LWPOLYLINE | 6 | Complex boundaries (fences, walls) |
| POINT | 1 | Single reference point |
| SOLID | 1 | Filled triangle (arrowhead in RNZICE block) |

## Block Definitions (Survey Symbols)

12 blocks defined, representing standard Czech geodetic symbols:

| Block | Inserts | Description |
|---|---|---|
| 1$09 | 98 | Small circle (r=0.15) — spot elevation marker |
| SIT | 9 | Crosshair (+) shape — situational point |
| 3$04 | 8 | Circle + horizontal line — tree/vegetation symbol |
| 3$13 | 7 | Nested arcs — boundary detail point |
| 4$02 | 4 | Tiny circle (r=0.175) — survey control point |
| 2$18 | 3 | Two opposing arcs — utility/pipe symbol |
| RNZICE | 1 | Large circle + crosshair + directional lines — benchmark/reference point |
| 3$14 | 1 | V-shape polyline + 2 circles — gate/entrance symbol |
| 6$20 | 1 | Unit circle — manhole/well symbol |
| 1$07 | 1 | Arc-based — boundary marker |
| 1$051 | 2 | Nested block with scaled insert — composite boundary marker |
| 1$052 | 1 | Nested block with scaled insert — composite boundary marker |

## Text Content

### Parcel Numbers (layer 18/19)
154/4, 154/5, 154/6, 154/8, 154/10, 154/11, 154/15, 154/16, 157/19, 288/165, 562/6, 699, 113, 129

### Spot Elevations (layers 22/41)
~93 values ranging from 392.72 m to 399.60 m ASL. The site slopes generally from NW (~399 m) to SE (~393 m).

### Survey Point IDs (layer 23)
Sequential numbers 1 through 93, plus supplementary points 4001-4004.

### Surface / Land-Use Labels
- `chodnik` — sidewalk/path
- `asfaltova komunikace` — asphalt road
- `vjezd` — driveway/entrance
- `zelen` — greenery
- `RIS` — utility marker

### Grid Coordinates (layer 61)
X labels: 717330, 717390
Y labels: 1059600, 1059630, 1059660

## Linetypes Defined
ByBlock, ByLayer, Continuous, Dot, Hidden, Dashed, DashDot, Divide, Center

## Text Styles Defined
ITALICT, MONOTXT, STANDARD

## Relationship to Project

- The project's elevation reference is +/-0,000 = 397.402 m ASL (Bpv), which falls within the surveyed elevation range
- The target parcels for the building permit are **154/10** and **154/16**, both visible in this survey
- The survey covers the surrounding context parcels needed for the site plans (C.1-C.4)

## Note on the DWG File

The `10225.dwg` file (56 KB) is the original binary AutoCAD drawing. It likely contains a paper space layout with a title block, legend, surveyor's stamp, and certification — but we cannot read it directly with ezdxf (which only handles DXF). To access the paper space content, the DWG would need to be:
1. Opened in AutoCAD and exported as DXF, or
2. Converted using the ODA File Converter (free tool from Open Design Alliance)

## Visualization

A visualization script (`dwg-files/visualize_dxf.py`) and rendered PNG (`dwg-files/10225_visualization.png`) are available. The script is generic and works with any DXF file:

```
python visualize_dxf.py [file.dxf]
```

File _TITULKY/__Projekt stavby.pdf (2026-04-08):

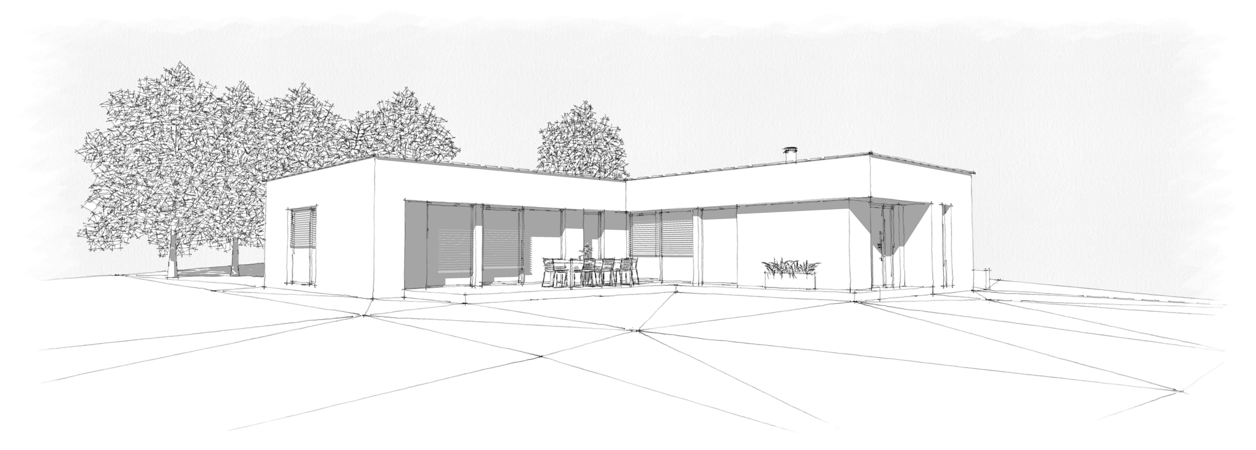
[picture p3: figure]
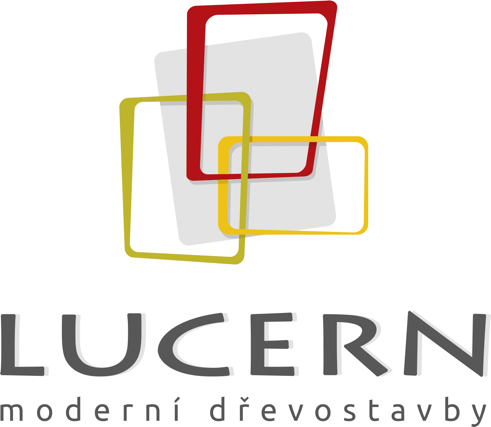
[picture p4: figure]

GSPublisherVersion 610.4.6.32

DATUM

VEDOUCÍ PROJEKTU

AUTORIZACE

VYPRACOVAL

# PROJEKT STAVBY

Ing. Václav Křepelák, DiS.

Ing. Miloš Slavík

LUCERN DŘEVOSTAVBY s.r.o.
ÚDOLNÍ 280/15
PRAHA 4 - BRANÍK
147 00

STUPEŇ PD

STAVBA

OBEC

INVESTOR

NOVOSTAVBA RODINNÉHO DOMU

DSP+DPS

Jevany [533378]

09/2025

Ing. Josef Frydrýn

parc. č. 154/10 a 154/16
k.ú.: Jevany [659312]

Bc. Markéta Edwards,
K dálnici 167, Pitkovice,
104 00 Praha 10

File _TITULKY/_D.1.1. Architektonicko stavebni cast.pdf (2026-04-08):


GSPublisherVersion 610.4.6.32

DATUM

VEDOUCÍ PROJEKTU

AUTORIZACE

VYPRACOVAL

D.1.1.

Ing. Václav Křepelák, DiS.

Ing. Miloš Slavík

LUCERN DŘEVOSTAVBY s.r.o.
ÚDOLNÍ 280/15
PRAHA 4 - BRANÍK
147 00

STUPEŇ PD

STAVBA

OBEC

INVESTOR

NOVOSTAVBA RODINNÉHO DOMU

DSP+DPS

Jevany [533378]

09/2025

Ing. Josef Frydrýn

parc. č. 154/10 a 154/16
k.ú.: Jevany [659312]

VÝKRES
ARCHITEKTONICKO STAVEBNÍ ČÁST

DATUM

VEDOUCÍ PROJEKTU

AUTORIZACE

VYPRACOVAL

D.1.1.

Ing. Václav Křepelák, DiS.

Ing. Miloš Slavík

LUCERN DŘEVOSTAVBY s.r.o.
ÚDOLNÍ 280/15
PRAHA 4 - BRANÍK
147 00

STUPEŇ PD

STAVBA

OBEC

INVESTOR

NOVOSTAVBA RODINNÉHO DOMU

DSP+DPS

Jevany [533378]

09/2025

Ing. Josef Frydrýn

parc. č. 154/10 a 154/16
k.ú.: Jevany [659312]

VÝKRES
ARCHITEKTONICKO STAVEBNÍ ČÁST

Bc. Markéta Edwards,
K dálnici 167, Pitkovice,
104 00 Praha 10

Bc. Markéta Edwards,
K dálnici 167, Pitkovice,
104 00 Praha 10

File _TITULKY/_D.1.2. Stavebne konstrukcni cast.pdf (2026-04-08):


GSPublisherVersion 610.4.6.32

DATUM

VEDOUCÍ PROJEKTU

AUTORIZACE

VYPRACOVAL

D.1.2.

Ing. Petr Fait

Ing. Miloš Slavík

LUCERN DŘEVOSTAVBY s.r.o.
ÚDOLNÍ 280/15
PRAHA 4 - BRANÍK
147 00

STUPEŇ PD

STAVBA

OBEC

INVESTOR

NOVOSTAVBA RODINNÉHO DOMU

DSP+DPS

Jevany [533378]

09/2025

Ing. Josef Frydrýn

parc. č. 154/10 a 154/16
k.ú.: Jevany [659312]

VÝKRES
STAVEBNĚ KONSTRUKČNÍ ČÁST

DATUM

VEDOUCÍ PROJEKTU

AUTORIZACE

VYPRACOVAL

D.1.2.

Ing. Miloš Slavík

LUCERN DŘEVOSTAVBY s.r.o.
ÚDOLNÍ 280/15
PRAHA 4 - BRANÍK
147 00

STUPEŇ PD

STAVBA

OBEC

INVESTOR

NOVOSTAVBA RODINNÉHO DOMU

DSP+DPS

Jevany [533378]

09/2025

Ing. Josef Frydrýn

parc. č. 154/10 a 154/16
k.ú.: Jevany [659312]

VÝKRES
STAVEBNĚ KONSTRUKČNÍ ČÁST

Ing. Petr Fait

Bc. Markéta Edwards,
K dálnici 167, Pitkovice,
104 00 Praha 10

Bc. Markéta Edwards,
K dálnici 167, Pitkovice,
104 00 Praha 10

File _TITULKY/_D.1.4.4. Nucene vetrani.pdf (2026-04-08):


GSPublisherVersion 610.4.6.32

DATUM

VEDOUCÍ PROJEKTU

AUTORIZACE

VYPRACOVAL

D.1.4.4.

Ing. Václav Křepelák, DiS.

Ing. Miloš Slavík

LUCERN DŘEVOSTAVBY s.r.o.
ÚDOLNÍ 280/15
PRAHA 4 - BRANÍK
147 00

STUPEŇ PD

STAVBA

OBEC

INVESTOR

NOVOSTAVBA RODINNÉHO DOMU

DSP+DPS

Jevany [533378]

09/2025

Ing. Josef Frydrýn

parc. č. 154/10 a 154/16
k.ú.: Jevany [659312]

VÝKRES
NUCENÉ VĚTRÁNÍ

DATUM

VEDOUCÍ PROJEKTU

AUTORIZACE

VYPRACOVAL

D.1.4.4.

Ing. Václav Křepelák, DiS.

Ing. Miloš Slavík

LUCERN DŘEVOSTAVBY s.r.o.
ÚDOLNÍ 280/15
PRAHA 4 - BRANÍK
147 00

STUPEŇ PD

STAVBA

OBEC

INVESTOR

NOVOSTAVBA RODINNÉHO DOMU

DSP+DPS

Jevany [533378]

09/2025

Ing. Josef Frydrýn

parc. č. 154/10 a 154/16
k.ú.: Jevany [659312]

VÝKRES
NUCENÉ VĚTRÁNÍ

Bc. Markéta Edwards,
K dálnici 167, Pitkovice,
104 00 Praha 10

Bc. Markéta Edwards,
K dálnici 167, Pitkovice,
104 00 Praha 10

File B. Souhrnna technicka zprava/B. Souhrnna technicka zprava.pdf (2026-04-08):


GSPublisherVersion 610.4.6.32

DATUM

VEDOUCÍ PROJEKTU

AUTORIZACE

VYPRACOVAL

B.

Ing. Václav Křepelák, DiS.

Ing. Miloš Slavík

LUCERN DŘEVOSTAVBY s.r.o.
ÚDOLNÍ 280/15
PRAHA 4 - BRANÍK
147 00

STUPEŇ PD

STAVBA

OBEC

INVESTOR

NOVOSTAVBA RODINNÉHO DOMU

DSP+DPS

Jevany [533378]

09/2025

Ing. Josef Frydrýn

parc. č. 154/10 a 154/16
k.ú.: Jevany [659312]

VÝKRES
SOUHRNNÁ TECHNICKÁ ZPRÁVA

Bc. Markéta Edwards,
K dálnici 167, Pitkovice,
104 00 Praha 10

### SOUHRNNÁ TECHNICKÁ ZPRÁVA – NOVOSTAVBA RODINNÉHO DOMU parc. č. 154/10 a 154/16, katastrální území: Jevany [659312]

## B.1Popis území stavby

a) charakteristika území a stavebního pozemku, zastavěné území a nezastavěné území, soulad navrhované stavby s charakterem území, dosavadní využití a zastavěnost území
Parcela leží v lokalitě, která je určena k zastavění, v katastru nemovitostí je vedena jako zahrada.
Pozemek je svažitý od severu k jihu. Parcela se nachází v zastavitelném území. Pozemek je oplocen.
Objekt svou výškou, objemem a proporcemi nenaruší prostor v dané lokalitě.
b) údaje o souladu s územním rozhodnutím nebo regulačním plánem nebo veřejnoprávní smlouvou územní rozhodnutí nahrazující anebo územním souhlasem
Dle platného územního plánu a navrženého funkčního využití ploch, je umístění navrženého rodinného
domu i garáže přípustné.
Návrh rodinného domu i garáže jsou v souladu s územním plánem obce Jevany. Parkování je navrženo na pozemku stavebníka. Jsou navrženy dvě parkovací místa na zpevněných plochách, případně v garáži.

Jedná se o individuální rodinný dům o jednom nadzemním podlaží.

Zastavěnost

Zastavěná plocha rodinného domu: 180,38 m²

Zpevněné plochy, terasa, garáž: 170,94 m²

Plocha pozemku celkem: 1 091 m²

Zastavěnost vč. zpevněných ploch: 351,32 m²

Zbylá zelená plocha pozemku: 739,68 m²

c) údaje o souladu s územně plánovací dokumentací, v případě stavebních úprav podmiňujících změnu v užívání stavby
Jedná se o novostavbu rodinného domu. Dle platného územního plánu města a navrženého funkčního využití ploch, je umístění navrženého rodinného domu přípustné.

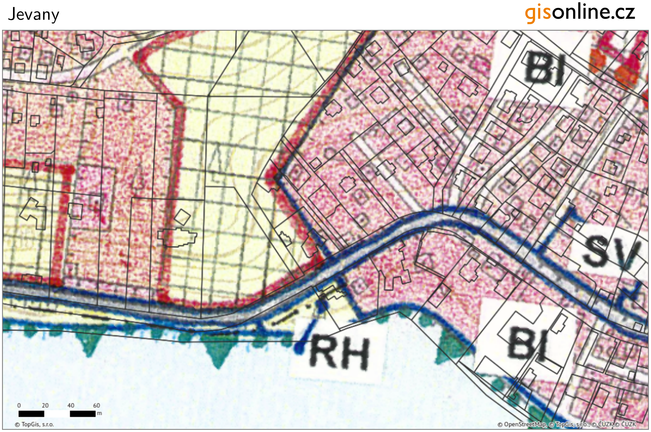
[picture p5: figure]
Jevany

Pozemek stavebníka se nachází v obci Jevany, katastrální území Jevany. Níže je uveden výňatek z územního plánu pro obec Jevany, který obec vydala. Dotčený pozemek se nachází dle územního plánu nachází v části BI: Bydlení individuální.

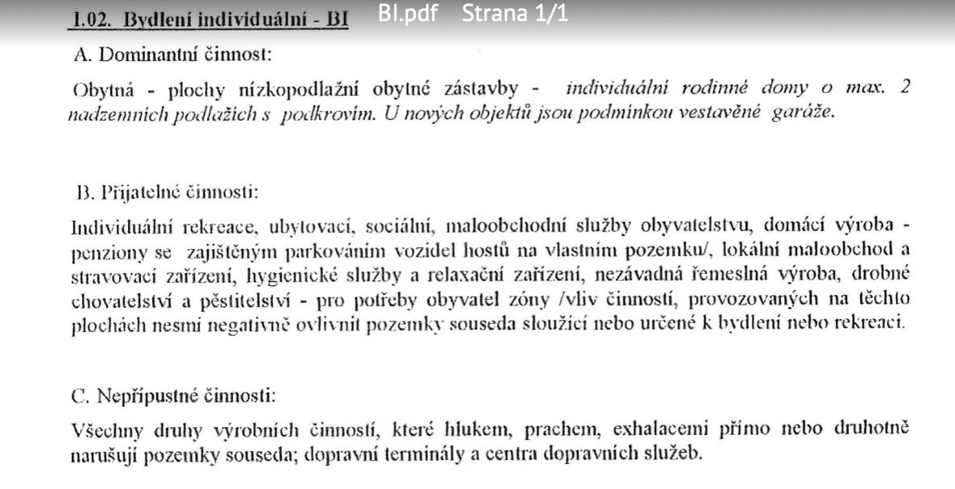
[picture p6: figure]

d) informace o vydaných rozhodnutích o povolení výjimky z obecných požadavků na využívání území V PD jsou splněny požadavky dané vyhláškou 360/2021 Sb. a vyhláškou 269/2009 Sb.
Umístění navržené stavby rodinného nevyžaduje žádné výjimky.
Rodinný dům je navržený na pozemku, který je schválený územním plánem, který vydala obec.
e) informace o tom, zda a v jakých částech dokumentace jsou zohledněny podmínky závazných stanovisek dotčených orgánů
Požadavky všech dotčených orgánů jsou v PD splněny.
f) výčet a závěry provedených průzkumů a rozborů (geologický průzkum, hydrogeologický
průzkum, stavebně historický průzkum apod.)
Pozemek bude při vytýčení stavby tachymetricky zpracován a polohopisně určen geodetem. Byl proveden geologický průzkum pro vsakování srážkových vod a doporučení pro návrh vsakovacího zařízení. Na pozemku bylo dále provedeno radonové měření – radonový index vysoký. Staveniště je možno označit jako vhodné. Jedná se o jednoduché základové poměry, kde se základová půda nemění v rozsahu staveniště.
g) ochrana území podle jiných právních předpisů (památková rezervace, památková zóna, zvláště chráněné území, záplavové území apod.)
Pozemek se nenachází v chráněném území.
Na pozemku se nenacházejí žádné zvláště chráněné druhy rostlin podle vyhlášky MŽP ČR č. 395/1992 Sb. z živočišných druhů se zde rovněž nevyskytují žádné zvláště chráněné.
V oblasti staveniště se nenacházejí ani ložiska nerostných surovin, chráněná ložisková území, dobývací prostory, prognózní zdroje nerostných surovin ani poddolovaná území.
Lokalita není součástí záplavového území.
h) poloha vzhledem k záplavovému území, poddolovanému území apod.
Pozemek se nenachází v záplavovém území ani poddolovaném území.
i) vliv stavby na okolní stavby a pozemky, ochrana okolí, vliv stavby na odtokové poměry v území Stavby nejsou podsklepené, jsou samostatně stojící o jednom nadzemním podlaží. Svojí výškou stavby zapadají do okolní zástavby. Stavby nemají vliv na okolní stavby a pozemky. Odtokové poměry území jsou řešeny na pozemku investora pomocí dešťové jímky s přepadem do vsakovacího zařízení.

Není potřeba zpracovávat posouzení vlivu dokončené stavby na životní prostředí dle přílohy č. 3, zákona č. 100 / 2001 Sb., o posuzování vlivu na životní prostředí ve znění pozdějších předpisů.

Činnosti, které by mohly obtěžovat okolí hlukem, budou prováděny v denních hodinách pracovních dnů. Po dobu provádění stavby nesmí být okolní prostor ovlivňován nadměrným hlukem, vibracemi a otřesy nad mez stanovenou v nařízení vlády č. 272/2011 Sb., o ochraně zdraví před nepříznivými účinky hluku a vibrací. Zhotovitel stavby je povinen během realizace stavby zajišťovat pořádek na staveništi a neznečišťovat veřejná prostranství, a v co největší míře šetřit stávající zeleň.V případě znečištění veřejných komunikací bude zajištěno jejich čištění. S odpady vznikajícími ze stavby bude nakládáno v souladu se zákonem č. 541/2020 Sb., o odpadech, v platném znění. Po ukončení stavby je zhotovitel povinen provést úklid všech ploch, které pro realizaci stavby používal a uvést je do původního stavu.

j) požadavky na asanace, demolice, kácení dřevin
Bez požadavků.

k) požadavky na maximální zábory zemědělského půdního fondu nebo pozemků určených k plnění funkce lesa, Zábory půdy nejsou předmětem dokumentace.
l) územně technické podmínky (zejména možnost napojení na stávající dopravní a technickou infrastrukturu), možnost bezbariérového přístupu k navrhované stavbě

Napojení na rozvody elektro (NN):
Stavba bude připojena na síť NN z pilířku v části uličního oplocení.
V pilířku je osazen elektroměrový jistič a hlavní nožové pojistky. Jištění 3 x 32 A.

Napojení na rozvody vody:
Stavba RD bude napojena na stávající vodovodní řad přes vodovodní šachtu.

Napojení na rozvody kanalizace:
Stavba RD bude napojena na stávající kanalizační řad přes kanalizační šachty.

Napojení na rozvody plynu:
Stavba RD nebude napojena na rozvody plynu.

Pošta:
Umístění poštovní schránky se uvažuje v linii vstupní branky.

Napojení na komunikaci:
Napojení RD je řešeno stávajícím sjezdem k veřejné komunikaci, která se nachází před pozemkem s řešeným objektem. Povrch přístupového chodníčku je navržen ze zámkové dlažby. Dvě parkovací místa jsou řešena na pozemku investora.

Vnější zpevněné plochy jsou navrženy jako bezbariérové a splňují požadavky dle vyhlášky 398/2009 Sb. Dále nejsou jiné požadavky na bezbariérovost.

m) věcné a časové vazby stavby, podmiňující, vyvolané, související investice Stavby nejsou vázány na realizaci jiné stavby, ani na jiné investice.
n) seznam pozemků na kterých se stavba provádí (podle katastru nemovitostí) Pozemek stavby je ve vlastnictví investora:
par. č..: 154/10 a 154/16 – zahrada (1 091 m²
)
o) seznam pozemků a staveb dotčených prováděním stavby (podle katastru nemovitostí) Sousední pozemky:

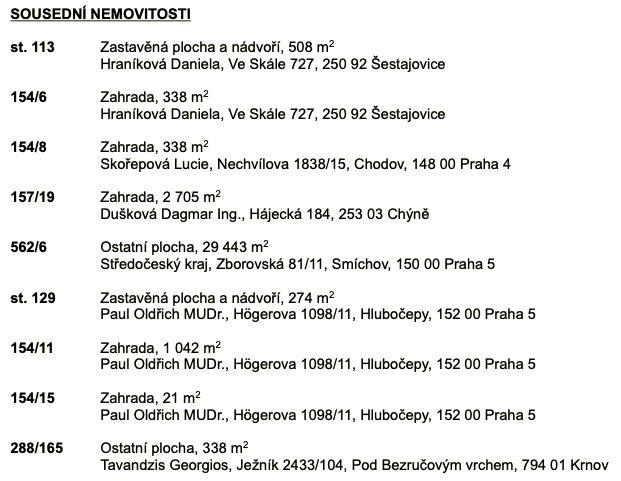
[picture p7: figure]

## B.2Celkový popis stavby

### B.2.1 Základní charakteristika stavby a jejího užívání

Záměrem investora (stavebníka) a obsahem předkládané projektové dokumentace je novostavba rodinného domu a garáže. Rodinný dům i garáž jsou navrženy s jednou bytovou jednotkou o dispozici 4+KK.
Jedná se o jednopodlažní dům zastřešený plochou střechou.
a) nová stavba nebo změna dokončené stavby Jedná se o novostavbu rodinného domu a garáže.
b) účel užívání stavby
Stavba RD je navržena k trvalému bydlení, stavba garáže pro parkování osobních automobilů.
c) trvalá nebo dočasná stavby
Stavby jsou trvalé.
d) informace o vydaných rozhodnutích o povolení výjimky z technických požadavků na stavby a technických požadavků zabezpečujících bezbariérové užívání stavby
Pro tuto stavbu nejsou žádné vydané výjimky, popř. úlevová řešení.
e) informace o tom, zda a v jakých částech dokumentace jsou zohledněny podmínky závazných stanovisek dotčených orgánů
Požadavky všech dotčených orgánů jsou v PD splněny.
f) údaje o ochraně stavby podle jiných právních předpisů1) (kulturní památka apod.)
Stavby nejsou kulturní památkou ani není požadována ochrana stavby dle jiných právních předpisů, než stanoví stavební zákon a OTP.
g) navrhované parametry stavby (zastavěná plocha, obestavěný prostor, užitná plocha, počet funkčních jednotek a jejich velikost, počet uživatelů/pracovníků apod.)
Je navržena stavba rodinného domu s 1 bytovou jednotkou.
a) | zastavěná plocha RD, terasy a zpevněných ploch, garáže: | 351,32 m²
b) | užitná plocha RD: | 142,07 m²
c) | obestavěný prostor: | 608,69 m³
d) | počet uživatelů: | 4 osoby
e) | výška hřebene od 0,000: | 3,41 m
h) základní bilance stavby (potřeby a spotřeby médií a hmot, hospodaření s dešťovou vodou, celkové produkované množství a druhy odpadů a emisí, třída energetické náročnosti budov apod.) Základní bilance stavby je uvedena v jednotlivých přílohách ZTI, vytápění a elektroinstalace.
i) základní předpoklady výstavby (časové údaje o realizaci stavby, členění na etapy)
Časový harmonogram prací vypracuje generální dodavatel stavby nebo bude určen investorem.
Jedná se pouze o rodinný dům. Nejprve bude provedeno založení objektu, poté bude provedena hrubá
| stavba, a nakonec dokončovací práce.
j) orientační náklady stavby
Generální dodavatel stavby vypracuje výkaz výměr vč. položkového rozpočtu.

### B.2.2 Celkové urbanistické a architektonické řešení

a) urbanismus - územní regulace, kompozice prostorového řešení
Jedná se o zástavbu v obytném území. Urbanistické prvky nejsou měněny. Rodinný dům je osazen jako solitér, stejně tak garáž.
b) architektonické řešení - kompozice tvarového řešení, materiálové a barevné řešení

Stavba rodinného domu je navržena podle zadání stavebníka. Rodinný dům je dispozičně řešen jako 4+KK. Objekt má jedno nadzemní podlaží. Objekt má jednoduchý tvar písmene L, o celkových půdorysných rozměrech 17,22 x 14,82 m. Rodinný dům je zastřešen plochou střechou se sklonem 2 %. Výška atiky ploché střechy rodinného domu vůči výškové kótě ±0,000 je na kótě 3,41 m. Objekt rodinného domu je navržen jako dřevostavba, založený na betonových pasech a železobetonové desce. Rodinný dům je stavba určená k bydlení a jedná se o trvalou stavbu. Rodinný dům je navržen pro potřeby užívání stavebníka. Navržená stavba plně respektuje charakter místa stavby i okolní zástavbu.
Stavba garáže je navržena podle zadání stavebníka. Objekt má jedno nadzemní podlaží. Objekt má jednoduchý tvar obdélníkový, o celkových půdorysných rozměrech 6,00 x 3,00 mGaráž je zastřešena také plochou střechou se sklonem 2 %. Výška atiky ploché střechy rodinného domu vůči výškové kótě ±0,000 je na kótě 2,75 m. Objekt garáže je navržen jako dřevostavba, založený na betonových pasech a železobetonové desce. Garáž je stavba určená k parkování osobních automobilů a jedná se o trvalou stavbu. Garáž je navržena pro potřeby užívání stavebníka. Navržená stavba plně respektuje
| charakter místa stavby i okolní zástavbu.

### B.2.3 Celkové provozní řešení, technologie výroby

Jedná se o projekt rodinného domu a garáže. Provozní řešení a technologie výroby není součástí projektové dokumentace.

### B.2.4 Bezbariérové užívání stavby

Stavba rodinného domu ani garáž nejsou určeny k užívání osobami s omezenou schopností pohybu a orientace a není navržena jako bezbariérová, což je v souladu s §2 vyhlášky 398/2009 Sb. ve znění pozdějších předpisů, která stanoví obecně technické požadavky zabezpečující užívání staveb osobami s omezenou schopností pohybu.

B.2.5 Bezpečnost při užívání stavby Stavby budou provedeny z certifikovaných materiálů výrobků.

Objekt rodinného domu vytváří pro uživatele stavby předpoklady pro dodržování bezpečného provozování stavby jejím užíváním, stejně tak stavba garáže.
Návrh stavby je z hlediska bezpečnosti navržen dle platných stavebně-technických, elektrotechnických, statických a požárně-bezpečnostních předpisů, zejména se jedná o:
* Stavební zákon č. 283/2021 Sb.
* Nařízení vlády č. 272/2011 Sb. O ochraně zdraví před nepříznivými účinky hluku a vibrací.
* Stavba bude prováděna podle všech platných bezpečnostních předpisů a podle schválené projektové dokumentace. Budou dodrženy požadavky na vybrané stavební výrobky, ve znění nařízení vlády č. 312/2005 Sb.

### B.2.6 Základní charakteristika objektů

a) stavební řešení
Rodinný dům i garáž jsou navrženy jako dřevostavba, založená na základových pasech a s železobetonovou základovou deskou.
b) konstrukční a materiálové řešení
Rodinný dům i garáž jsou navrženy jako rámová dřevostavba, založená na základových pasech s železobetonovou základovou deskou. Svislé konstrukce jsou opláštěné deskami Rigistabil. Osová vzdálenost sloupků je 625 mm. Prostor dutiny je vyplněn minerální tepelnou izolací. Zastřešení je tvořeno dřevěnými trámy. Jako střešní krytina je zvolena PVC folie krytina. Obvodové stěny RD jsou tvořeny dřevěnou sendvičovou konstrukcí.
c) mechanická odolnost a stabilita
Stavby jsou navrženy tak, aby zatížení na ni působící v průběhu výstavby a užívání nemělo za následek: zřícení stavby nebo její části, větší stupeň nepřípustného přetvoření, poškození jiných částí stavby nebo technických zařízení nebo instalovaného vybavení v důsledku většího přetvoření nosné konstrukce, poškození v případě, kdy je rozsah neúměrný původní příčině.
Veškeré stavební dílce jsou z tradičních materiálů, rozměrů a technologií. Statická únosnost stavebních materiálů je garantována výrobcem systému.
d) oplocení
Pozemek stavebníka je oplocen. Oplocení viz C.3.

### B.2.7 Základní charakteristika technických a technologických zařízení

a) technické řešení

Napojení na rozvody elektro (NN):
Stavba bude připojena na síť NN z pilířku v uliční části oplocení.
V pilířku je osazen elektroměrový jistič a hlavní nožové pojistky. Jištění 3 x 32 A.

Napojení na rozvody vody:
Stavba RD bude napojena na stávající vodovodní řad přes vodovodní šachtu.

Napojení na rozvody kanalizace:
Stavba RD bude napojena na stávající kanalizační řad přes kanalizační šachty.

Dešťová kanalizace bude napojena na dešťovou jímku s přepadem do vsakovacího zařízení.

Odvětrání prostor RD bude nucené, za pomoci rekuperační jednotky. Odvětrání prostor garáže bude zabezpečeno pomocí příčného, přirozeného větrání.

b) výčet technických a technologických zařízení
Řešení technických a technologických zařízení není předmětem projektové dokumentace.

### B.2.8 Zásady požárně bezpečnostního řešení

Viz samostatná část dokumentace D.1.3. Požární bezpečnost staveb.

### B.2.9 Úspora energie a tepelná ochrana

Viz Průkaz energetické náročnosti budovy.
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

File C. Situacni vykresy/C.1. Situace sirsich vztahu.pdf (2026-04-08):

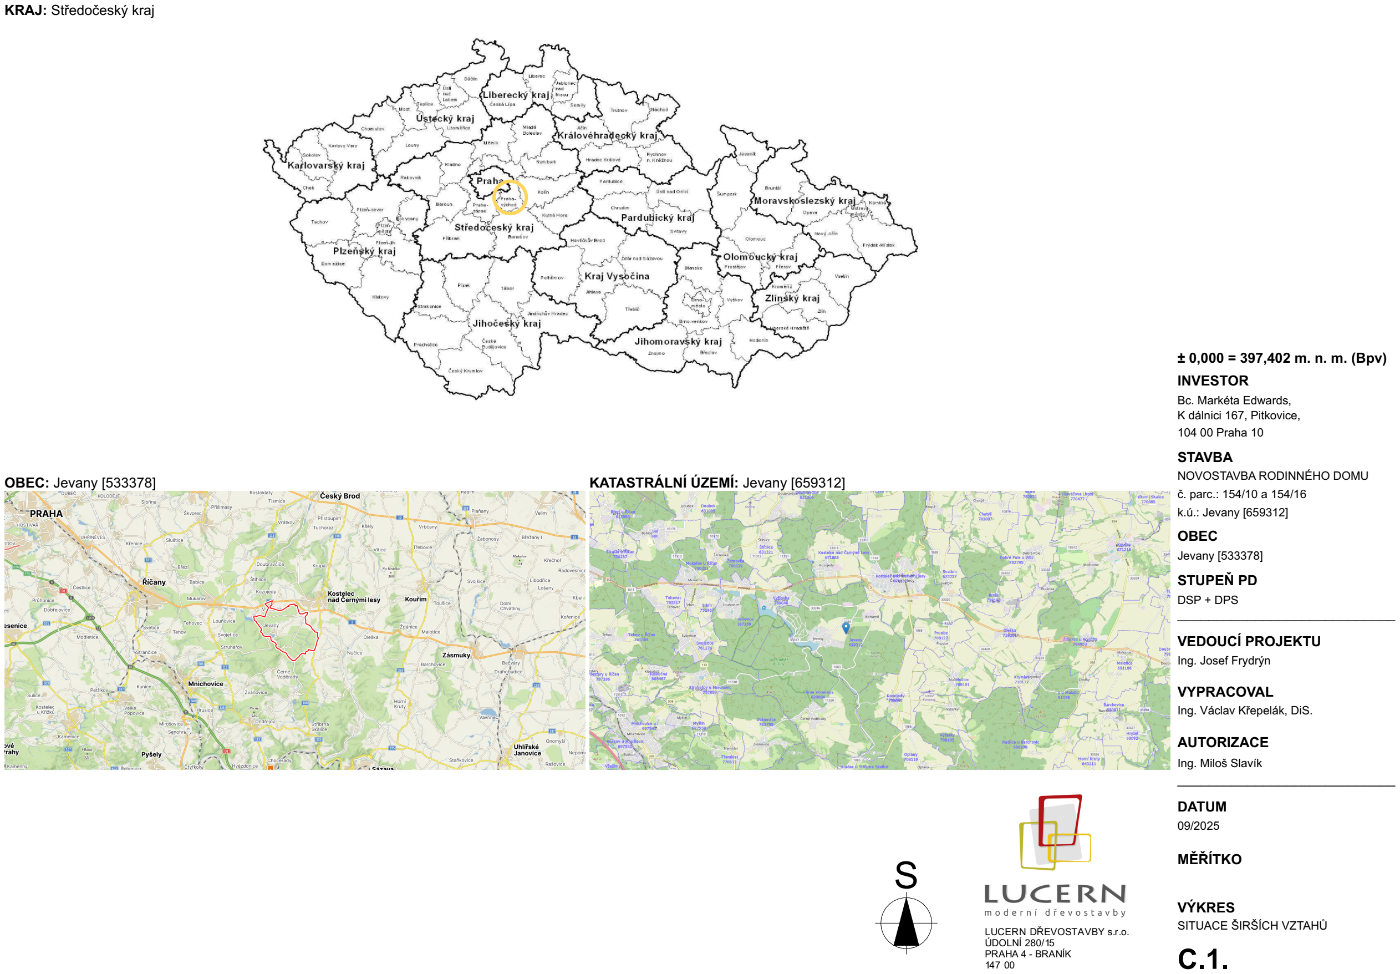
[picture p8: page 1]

GSPublisherVersion 610.4.6.32

S

MĚŘÍTKO

VÝKRES
SITUACE ŠIRŠÍCH VZTAHŮ
C.1.

VEDOUCÍ PROJEKTU
Ing. Josef Frydrýn

VYPRACOVAL
Ing. Václav Křepelák, DiS.

AUTORIZACE
Ing. Miloš Slavík
____________________________

DATUM
09/2025

____________________________

LUCERN DŘEVOSTAVBY s.r.o.
ÚDOLNÍ 280/15
PRAHA 4 - BRANÍK
147 00

± 0,000 = 397,402 m. n. m. (Bpv) INVESTOR
Bc. Markéta Edwards,

STAVBA
NOVOSTAVBA RODINNÉHO DOMU

k.ú.: Jevany [659312]
OBEC
Jevany [533378]
STUPEŇ PD
DSP + DPS

č. parc.: 154/10 a 154/16

K dálnici 167, Pitkovice,
104 00 Praha 10
OBEC: Jevany [533378] | KATASTRÁLNÍ ÚZEMÍ: Jevany [659312]

KRAJ: Středočeský kraj

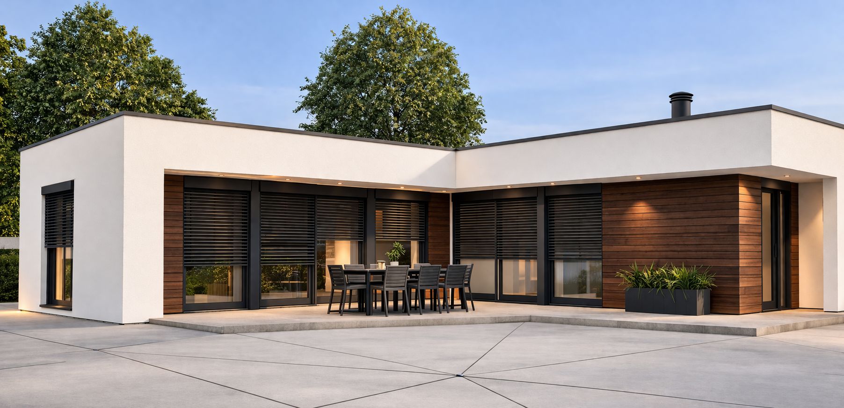
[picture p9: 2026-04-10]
Documents/images/lucern-house-jevany.jpeg

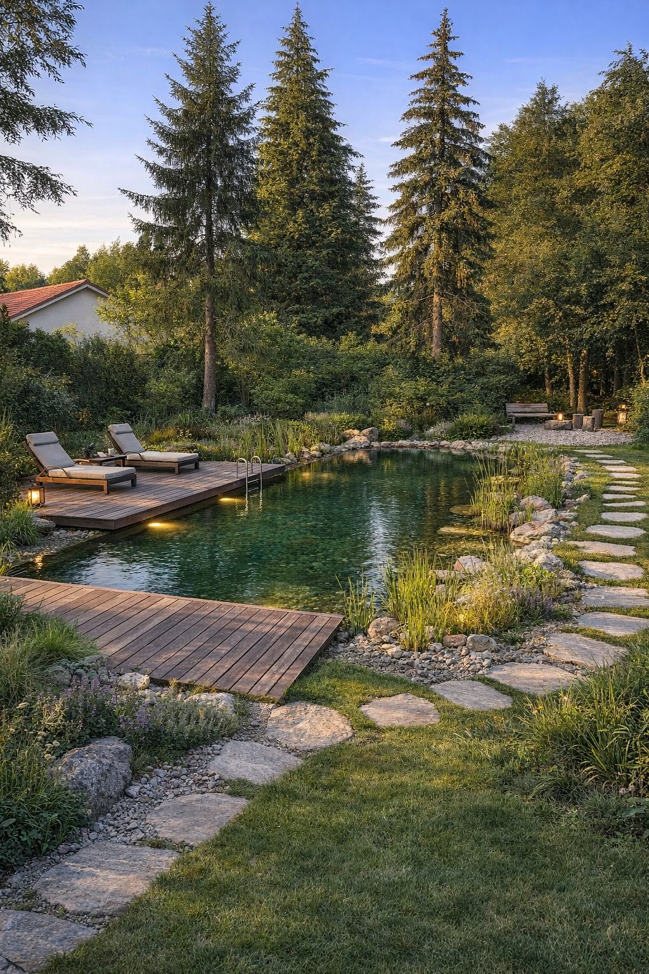
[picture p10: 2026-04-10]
Documents/images/natural-swimming-pond-jevany.jpeg

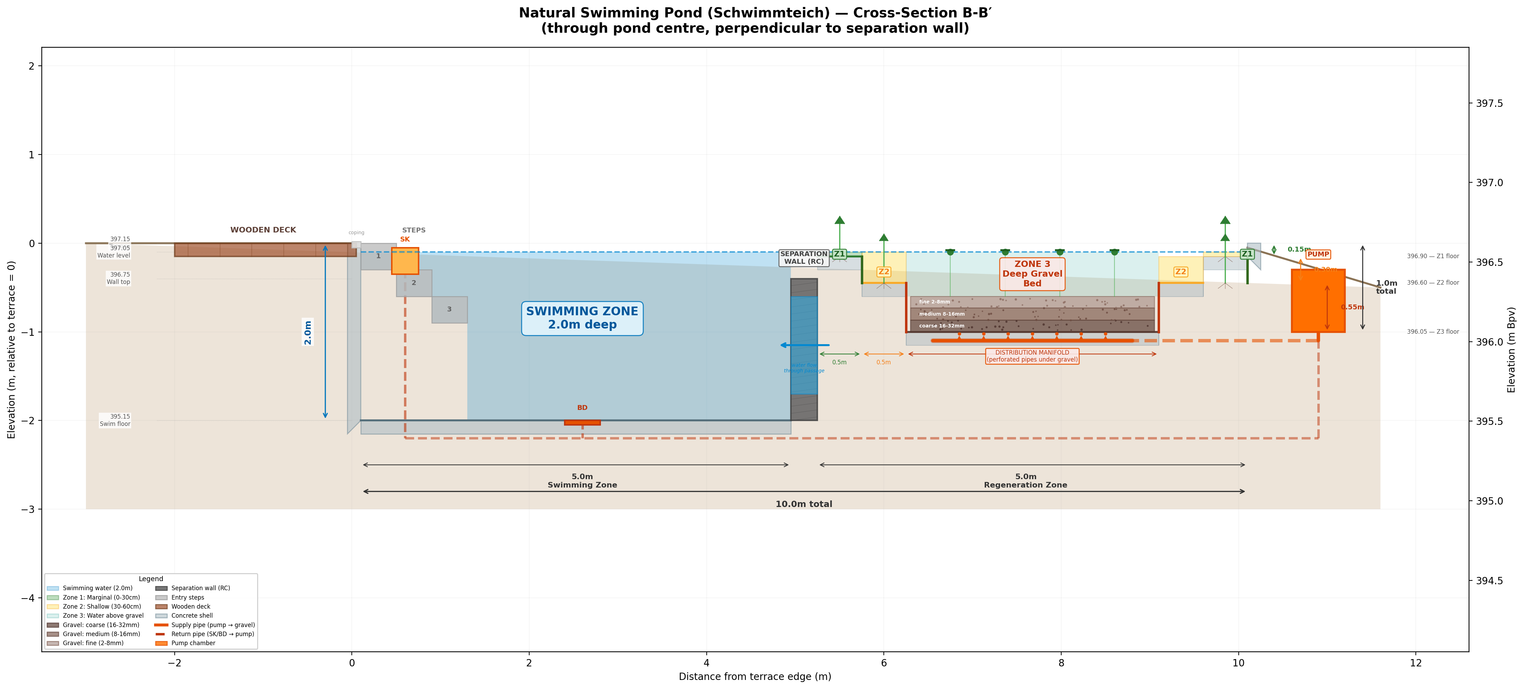
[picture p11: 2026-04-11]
Documents/dwg-files/schwimmteich_cross_section.png

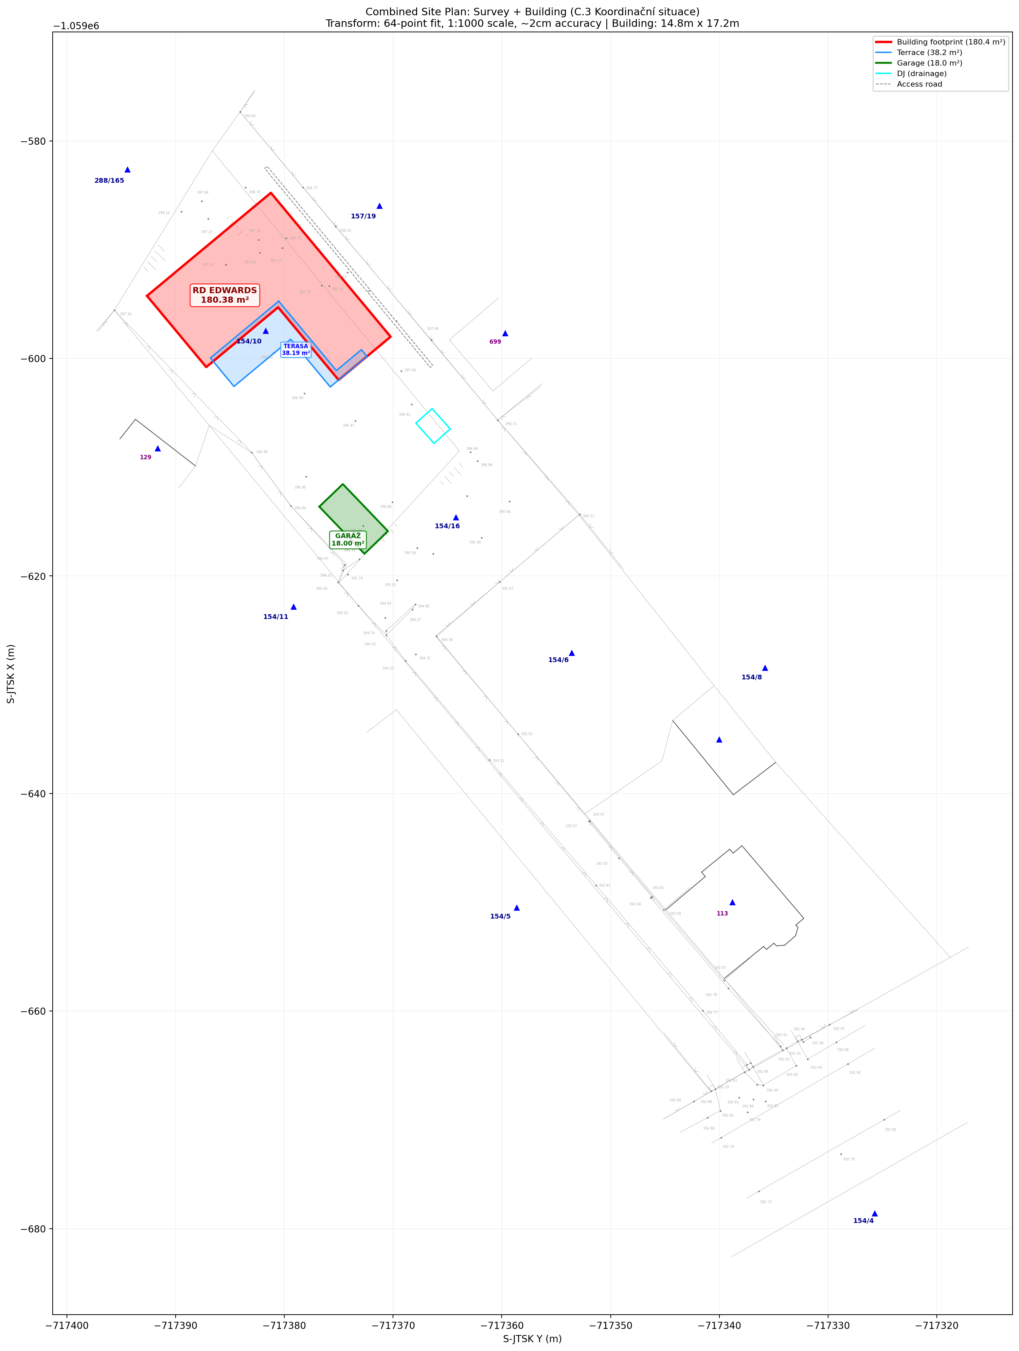
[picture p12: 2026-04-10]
Documents/dwg-files/combined_site_plan.png

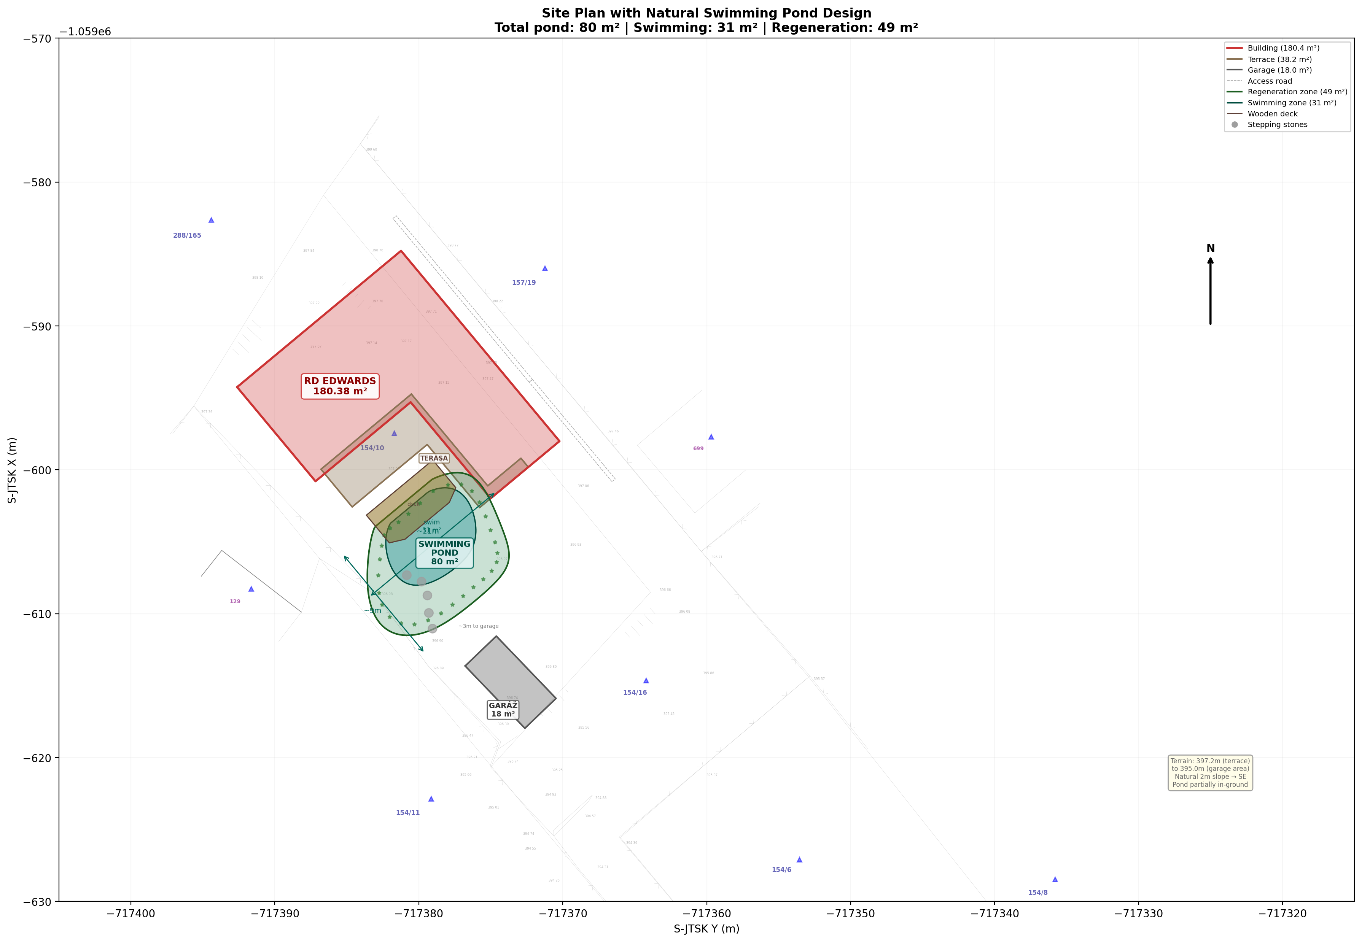
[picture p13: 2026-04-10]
Documents/dwg-files/site_plan_with_pond.png

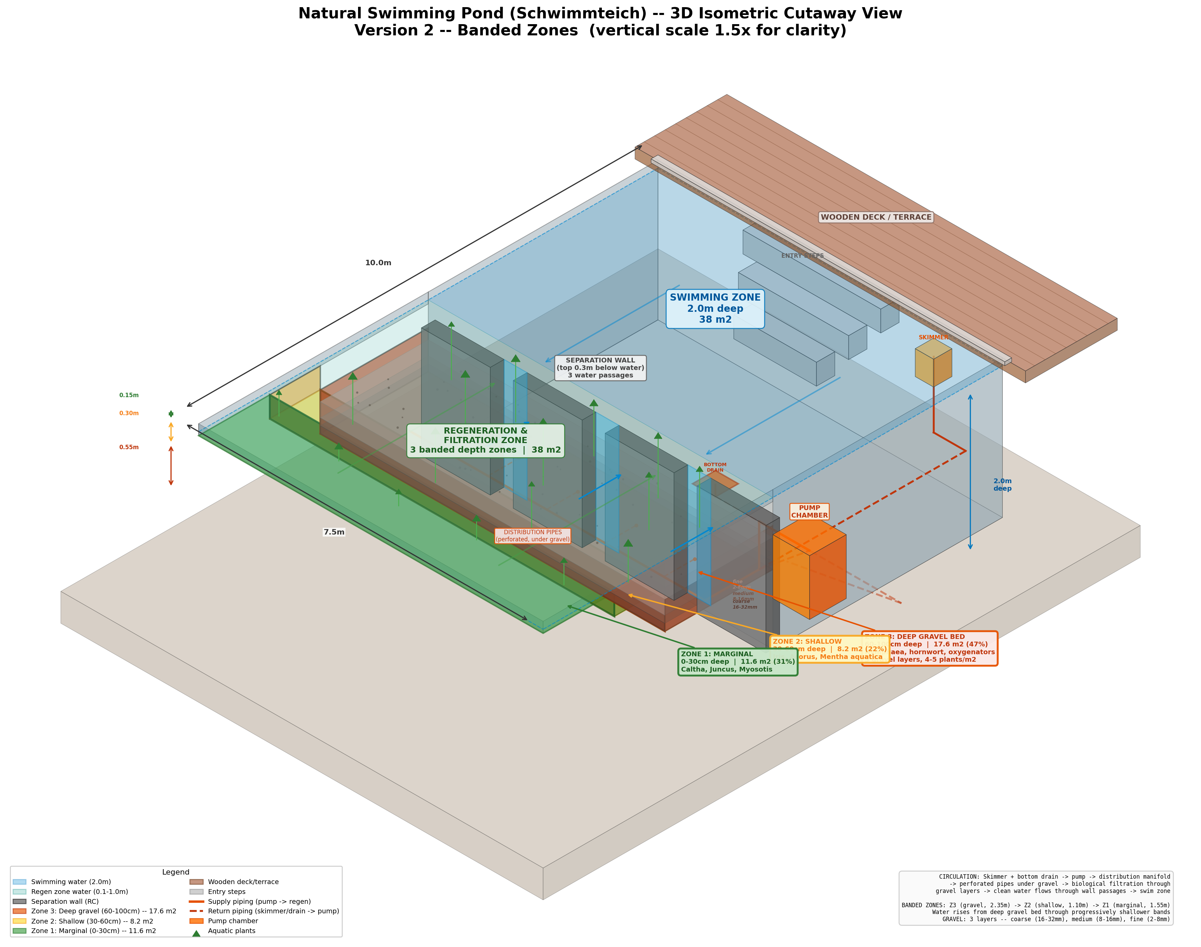
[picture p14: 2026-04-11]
Documents/dwg-files/schwimmteich_3d_isometric_v2.png

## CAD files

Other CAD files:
Documents/dwg-files/site_plan_with_pond.dxf
Documents/dwg-files/schwimmteich_plan_v3.dxf
Documents/dwg-files/C.3. Koordinacni situace.dxf
Documents/dwg-files/C.2. Celkovy situacni vykres.dxf
Documents/dwg-files/combined_site_plan.dxf
Documents/dwg-files/schwimmteich_plan.dxf
Documents/dwg-files/D.1.1.3. Pudorys 1. NP.dwg
Documents/dwg-files/10225.dxf
Documents/dwg-files/10225.dwg
Documents/dwg-files/C.2. Celkovy situacni vykres.dwg
Documents/dwg-files/C.3. Koordinacni situace.dwg

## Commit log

2026-04-08 Add survey plan analysis, DXF tools, and swimming pond feasibility study
    - Analyze geodetic survey plan (10225.dxf): terrain elevations, parcel
    boundaries, layers, blocks, and text content in S-JTSK coordinates
    - Add generic DXF visualization script (visualize_dxf.py)
    - Create site plan with approximate building placement (site_plan_with_building.dxf)
    - Document natural swimming pond feasibility based on geology, radon,
    drainage, and site plan data from the building permit documentation
    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
    [10225.dwg, 10225.dxf, site_plan_with_building.dxf]
2026-04-08 Document tools and services used in the project
    Add Tools & Services section to README covering Autodesk Viewer,
    CAD software, Python libraries, PDF processing, and coordinate systems.
2026-04-10 DWG filez from LUCERN
    [C.2. Celkovy situacni vykres.dwg, C.3. Koordinacni situace.dwg, D.1.1.3. Pudorys 1. NP.dwg]
2026-04-10 Add schwimmteich/pond site plans, DXF generation scripts, and update docs
    Replace old site_plan_with_building with new Czech site plans and schwimmteich
    pond designs. Add Python scripts for generating combined and pond DXF plans,
    plus an image generation prompt doc.
    [C.2. Celkovy situacni vykres.dxf, C.3. Koordinacni situace.dxf, combined_site_plan.dxf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]
2026-04-11 Add 3D isometric views, cross-sections, and technical design spec for swimming pond
    Two layout variants (v1: concentric ring zones, v2: banded zones) with
    3D isometric cutaway views and detailed cross-sections showing the three
    regeneration depth zones, gravel substrate layers, piping, and circulation.
    Includes full technical design specification document referencing research.
    [schwimmteich_plan_v2.dxf]
2026-04-11 Consolidate project documents and update README
    Replace separate feasibility, geotechnical, technical spec, DWG request,
    and DXF workflow documents with three consolidated docs: Project Design
    Document, CAD Workflow and File Status, and Natural Swimming Ponds Reference.
    Update README links to match the new document structure.
